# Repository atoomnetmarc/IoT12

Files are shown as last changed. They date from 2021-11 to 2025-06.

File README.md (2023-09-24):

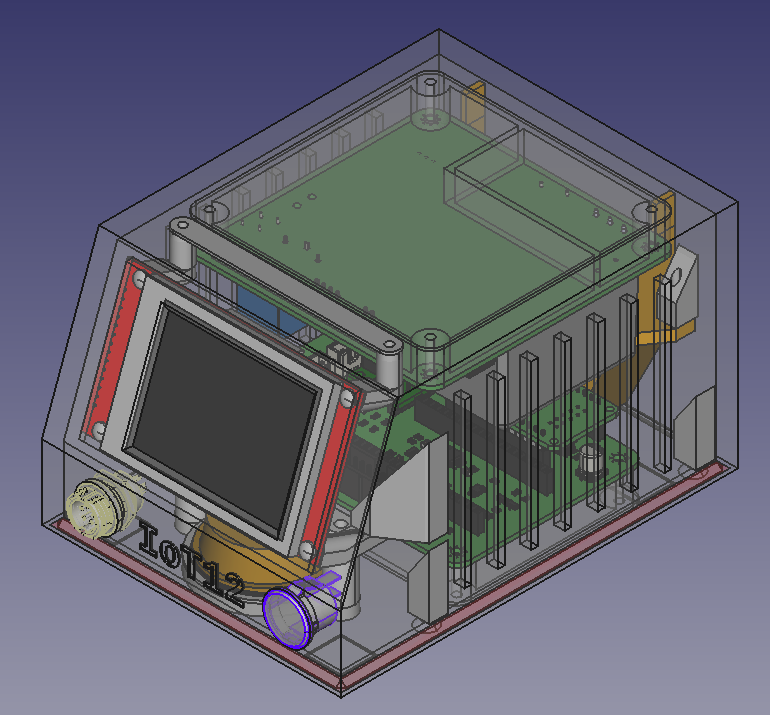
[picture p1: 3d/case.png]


# Hi!

This is an attempt at creating a soldering iron controller that uses T12 tips for a soldering iron handle with GX12-5 connector (KSGER FX9501 Handle). The pinout of the GX12-5 connector should match [this table](#control-board-j5-to-gx12-5-connector).

The name IoT12 is a portmanteau of IoT (because this soldering iron controller is connected to the internet using WiFi) and T12 (the type of soldering iron tip).

Have a look at the different elements that make up this project:

- [3d models for the case](3d/)
- [firmware for the heat controller and main processor](firmware/)
- [schematic and pcb](hardware/)

# Status

**Experimental and incomplete. Do not replicate yet.**

**You should be present at all times when using this project in case something goes wrong.**

# Assembly

You will need to 3d print all the parts mentioned in [3d](3d/README.md) directory.

You will need the 3 PCBs mentioned in the [hardware](hardware/README.md) directory.

# Cable harness

You need to crimp some JST-XH connectors and an IDC cable. Except for the IDC cable, use a wire diameter that can carry 3A. I used 0.2mm² (24 AWG, RS PRO series stranded tinned copper conductor equipment wire with PVC insulation).

## Power supply J2 to power switch

Cut 2 pieces of 14cm (5 33/64 inch) wire and crimp JST-XH pin on 1 end. Then plug into JST-XHP-2 connector. Solder the other end to a 16mm round rocker switch.

| Pin | Description | Wire color |
| --: | -- | -- |
| 1 | To power switch | Purple |
| 2 | To power switch | Purple |

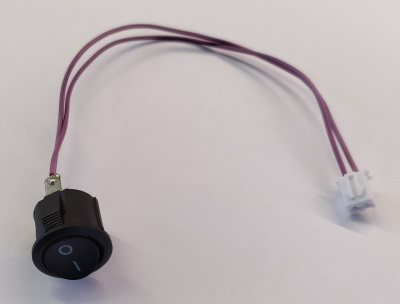
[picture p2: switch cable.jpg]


## Power supply J3 to Control Board J4

Cut 4 pieces of 14cm wire and crimp JST-XH pin on both ends. Then plug into JST-XHP-4 connector.

| Pin | Description | Wire color |
| --: | -- | -- |
| 1 | +24V | Yellow |
| 2 | +5V | Red |
| 3 | GND | Black |
| 4 | +24V ON | Pink |

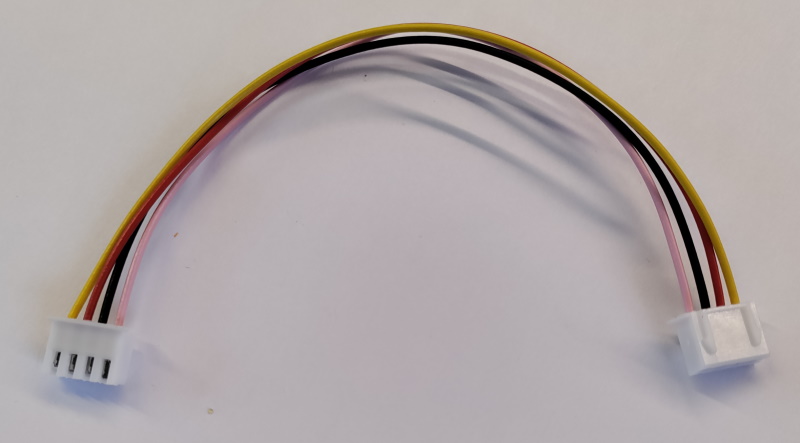
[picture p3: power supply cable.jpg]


## Control board J2 to speaker

Cut 2 pieces of 14cm wire and crimp JST-XH pin on 1 end. Then plug into JST-XHP-2 connector. Solder the other end to a 4cm speaker (4 ohm 3 watt)

| Pin | Description | Wire color |
| --: | -- | -- |
| 1 | To speaker | Brown |
| 2 | To speaker | Brown |

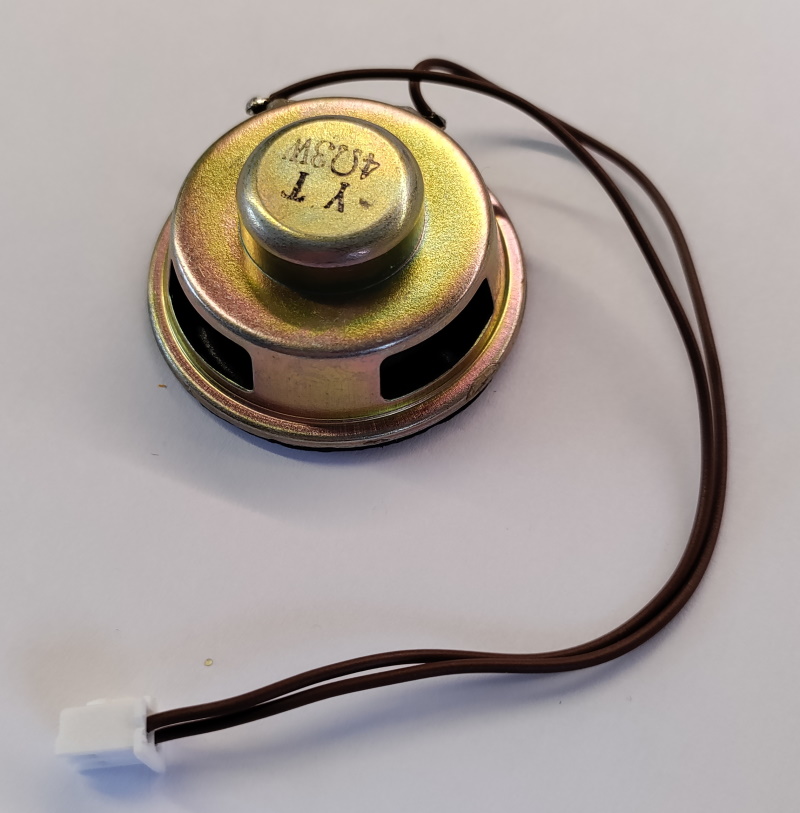
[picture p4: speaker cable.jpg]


## Control board J5 to GX12-5 connector

Cut 5 pieces of 14cm wire and crimp JST-XH pin on 1 end. Then plug into JST-XHP-52 connector. Solder other end to GX12-5 connector.

| Pin | Description | Wire color |
| --: | -- | -- |
| 1 | shake | Blue |
| 2 | NTC | White |
| 3 | ESD | Green |
| 4 | T12- | Black |
| 5 | T12+ | Red |

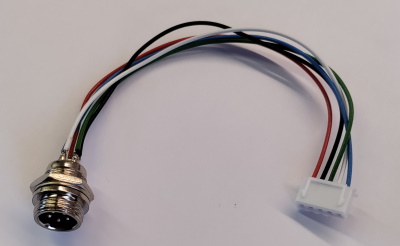
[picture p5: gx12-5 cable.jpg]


## Control board J1 to Display Adapter J1

Cut a 14 cm 14-pin 1.27mm pitch ribbon cable. Crimp a IDC-14 connector on both ends. You should orient both connectors so that one polarizing key points away from the center of the cable and the other points to the center of the cable. Please note that pin 1 of the cable should align with pin 1 on both connectors (indicated by a triangle on the connector).

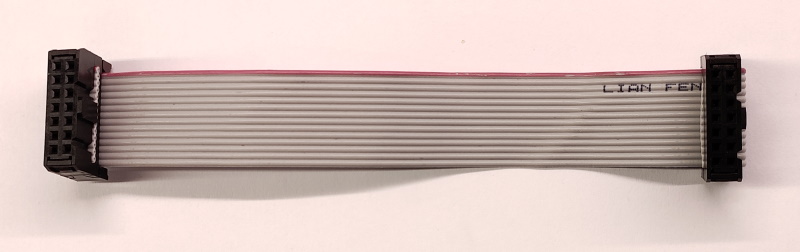
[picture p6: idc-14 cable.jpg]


# Testing

Connect a (KSGER) T12 solder iron handle with the T12 tip (really) firmly seated inside to the GX12-5 socket. The JST-XH connector should connected to the control pcb. The power supply board should be connected to to the control pcb, but not powered on.

Measure about 60kΩ between the tip of the iron and GND on the control board (J6).

Measure 1MΩ between the tip of the iron and EARTH pin at the Power supply board (J1).

Now measure some values at the solder iron connector J5.\
The heater resistor between 4 (black) and 5 (red): 8Ω.\
Not 8Ω? Now retry and really push in the T12 tip into the handle.

Switch over to measure mV and measure 4 (black) and 5 (red) again. When you have not touched the handle and tip for half an hour you should read 0mV. Grab the cold T12 tip with your hand. You should notice an increasing voltage, possibly a rise until 0.1mV. It is possible your voltmeter is not capable of measuring in the microvolt range. You can heat the tip with a flame for a few seconds to increase the voltage some more.

Measure the NTC between 4 (black) and 2 (white): 5KΩ at 22°C (71.6°F) room temperature, but resistance could vary slightly when not measuring at 22°C.

Test the tilt sensor. Point soldering iron up and measure between 1 (blue) and 3 (green). You are measuring around 250kΩ.\
Point iron down and measure a low resistance of less than 100Ω.

The soldering iron handle is now validated to be correctly connected and should function correctly.

Connect the speaker to J2 on the control board.

Connect the power switch to J2 on the power supply board.

Connect display adapter J1 to control board J1.

Modules A1 and A3 should not be plugged in yet. All other connectors are plugged in.

Apply current limited (100mA) 24V with your lab power supply to the right leg of F1 on the power supply board (and gnd on some other pin like the middle pin of U1). Apply the 24V slowly starting at 0V. Stop at 6V. Measure the 5V pin on J4 (it should be 5.2V), notice LED D4 also lit up. Continue increasing to 24V. Current should stay below 10mA. Turn off lab power supply.

When all tests went well flash [the firmware](firmware/README.md) to both A1 (ESP32) and A3 (SAMD21). Do not plug in the modules in the control board before flashing the firmware.

Plug in A1 and A3. Both USB connectors should point to the center of the control board.
Again apply current limited 24V. But now increase the limit to 250mA. At about 6V the display should turn on. Both blue LEDs on A3 and the red LED on A3 should also light up. Current is now about 200mA. Increase until 24V. Current is now about 60mA.\
Measure the 3V3 pin on J6, it should measure 3.3V.

If your power supply can handle 3.5A at 24V you could try enable heating of the soldering iron. To enable heating you must switch on the power switch connected to J2 on the power supply board.

If you came this far and all tests went well, go reward yourself with your favorite drink or snack. Happy.

# Final assembly

\<insert final assembly instructions here, something about fitting everything in the 3d printed case, hmm, maybe this is all the instuctions needed>



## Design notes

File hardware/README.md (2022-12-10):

# IoT12-hardware
Schematic and PCB files of the IoT12 solder iron temperature controller for T12 tips.

My [Kicad library](https://github.com/atoomnetmarc/ATOOMNETKICAD) is used in this project.

## [Control Board](Control%20Board/README.md)
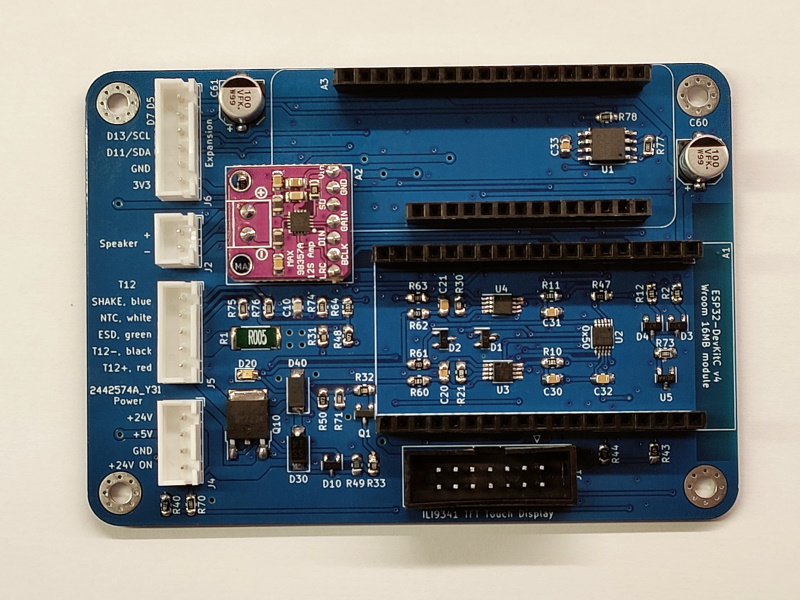
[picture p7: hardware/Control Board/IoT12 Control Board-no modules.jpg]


## [Power Supply](Power%20Supply/README.md)
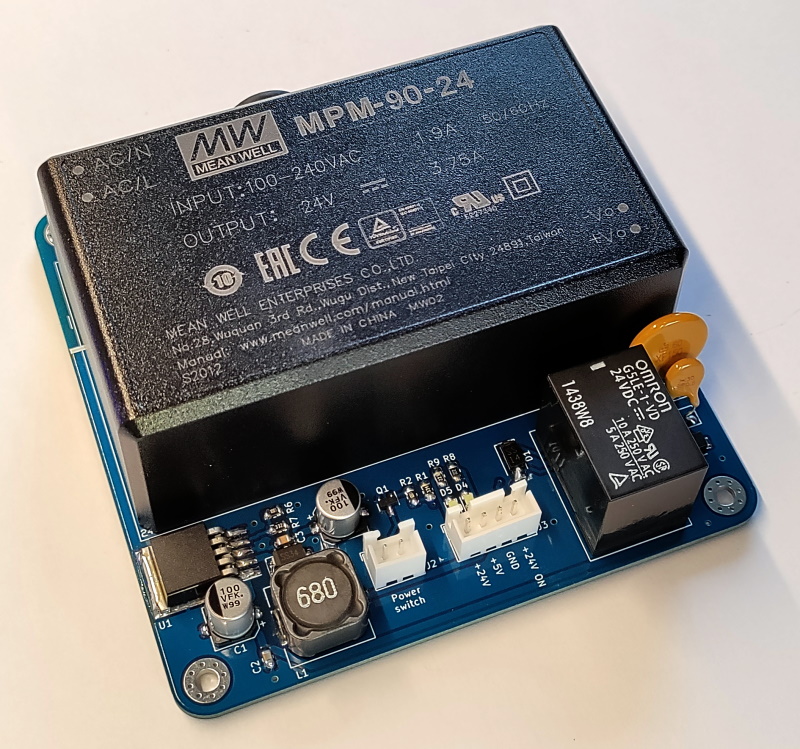
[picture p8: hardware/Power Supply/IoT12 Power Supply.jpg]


## [Display Adapter](Display%20Adapter/README.md)
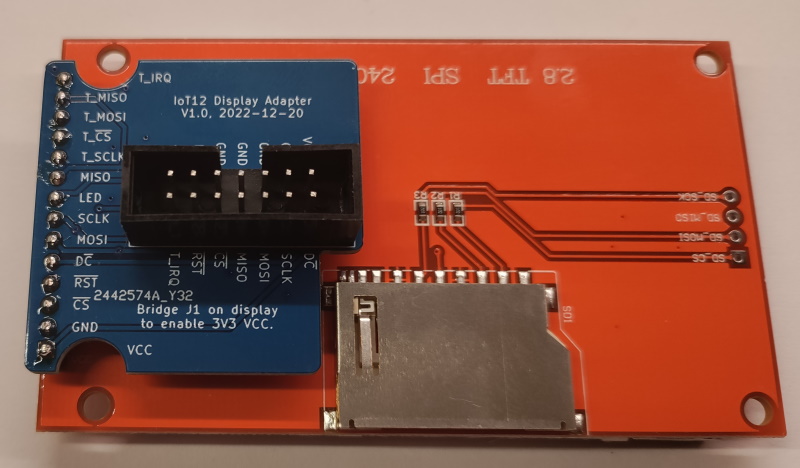
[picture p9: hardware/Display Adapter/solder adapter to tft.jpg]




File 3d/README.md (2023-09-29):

3d-models usable for the [IoT12](https://github.com/atoomnetmarc/IoT12) project.



[STLs here](stl/).

Use 6 black M3x10 counter sunk self tapping screws for mounting the lid and the C14 power socket.

Use 20 black M3x12 button head self tapping screws to mounting all other parts to the lid and the case.

Use 4 12x12mm sticky feed on bottom of lid.



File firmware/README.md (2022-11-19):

# Status

*Firmware is out of sync with the current version of control board and power supply. Grand me some time to work on things.*



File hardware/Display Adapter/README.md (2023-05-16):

Render

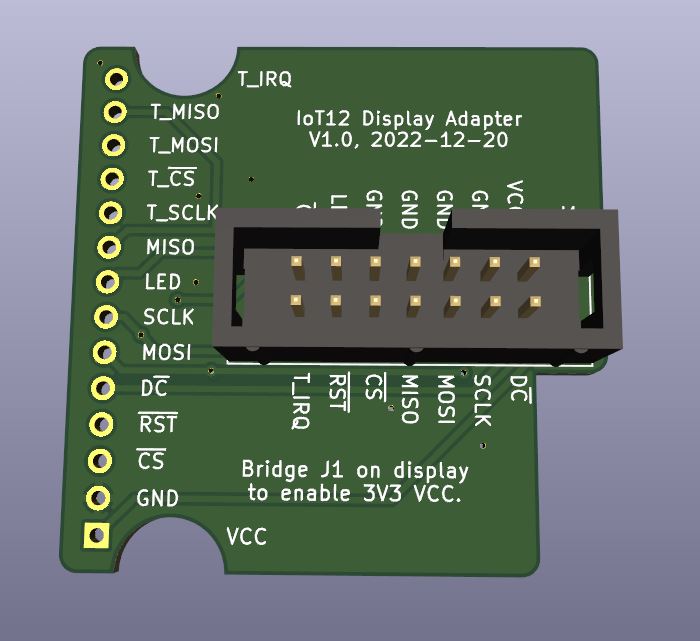
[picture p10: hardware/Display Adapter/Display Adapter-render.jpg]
Display adapter rendering


# Soldering

Yes, do it now. Use the [BOM](bom/ibom.html) for identifying the components.

Results:

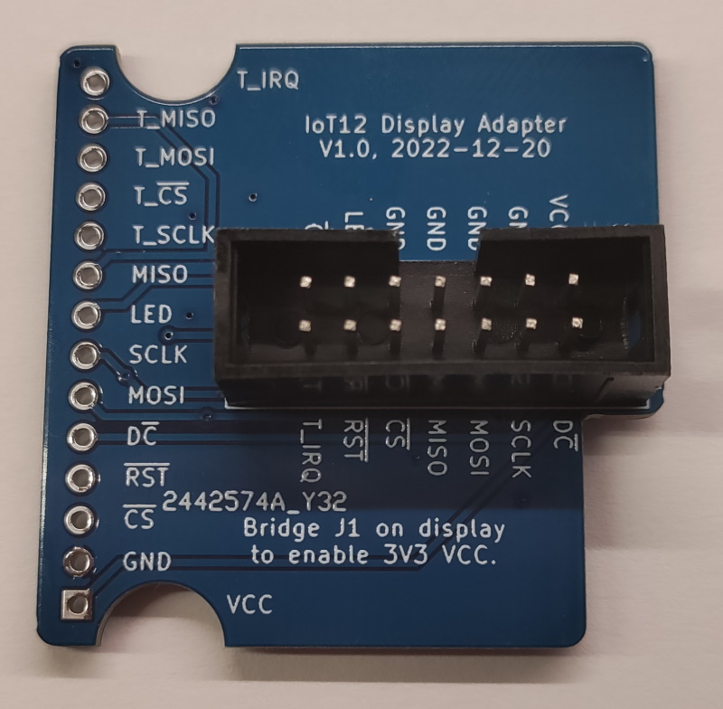
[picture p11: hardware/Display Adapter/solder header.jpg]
Yeah for soldering the only component on the BOM.


Stick a about 2.4mm high sticky pad on the bottom like this:

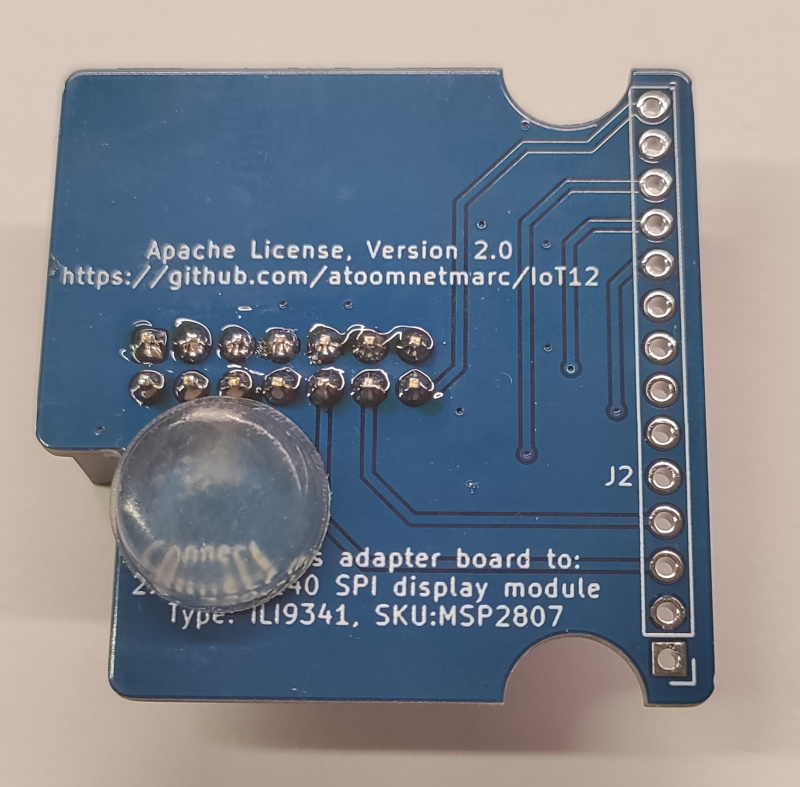
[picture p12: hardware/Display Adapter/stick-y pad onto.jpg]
I used a 4mm sticky pad.


Did you bridge J1 on the TFT pcb to enable 3.3V operation? Do that before soldering the adapter board onto the TFT.

Next, solder the adapter board onto the back of the TFT display:

Soldered adapter board to back of TFT display.



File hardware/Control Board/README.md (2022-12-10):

# Assembly instructions

Use the [interactive BOM](bom/ibom.html) to identify values and positions of the components.

Solder all small 0805 SMD resistors and capacitors.
Read special instructions for R60, R61 and R62, R63 in the schematic.

Measure all resistors and check if they are all the correct resistance.

Solder rest of SMD components.

Clean PCB.

Inspect PCB with microscope for shorted pins (in ICs). Correct when found.

Solder all through-hole components.

Clean PCB.

You now have something like this:



Apply current limited 5V to GND and +5V on J4. Almost no current should flow.

Apply current limited 3.3V to GND and 3V3 on J6. Almost no current should flow.

# Done

Done!

# Changelog

**Control board PCB version V2.2**

- Removed debug LED
- Removed 5110 LCD
- Removed rotary encoder
- Added header for 2.8" ILI9341 320x240 touch TFT
- Added relay for switching 24V
- Moved power supply circuitry to power supply PCB
- Removed small EEPROM
- Added SPI flash
- Added expansion header
- Layed out PCB again to fit on bottom lid of enclosure

**Control board PCB version V2.1**

- Swapped SDA/SCL I2C minion pins on heater controller.
- Swapped SDA/SCL I2C master pins on heater controller.
- Renamed PWM_HEAT to HEAT_PWM.
- Re-added MAX809S voltage monitor to keep ESP32 in reset if 3.3V is too low.
- Dimensioned F1 to 50% of Amax of T12-tip, see notes in schematic.
- Connected Vin ADC to after F1.
- Moved USB connector and reset button of heater controller.

**Control board PCB version V2.0**

- Replace safety features by microcontroller.
- Heating control now done by microcontroller.
- Changed shape and layout of pcb.

**Control board PCB version V1.1**

- Added explanation to schematic about using matched resistors for the instrumentation amplifiers.
- Changed gain resistors of the instrumentation amplifiers as to keep Vout under 1V at full scale input.
- Added series diode to output of voltage monitor.
- Lowered value of C2-C5 from 10nF to 1nF.
- Added D9 and D10.
- Changed value of R9 from 100R to 1k
- Added circuit to shutdown heating in case of overheating tip.

**Control board PCB version V1.0**

- First version that got made into PCB form.

# Eratta

**Control board PCB version V2.2**

No known erratum.

**Control board PCB version V2.1**

- It seems that after some use the 5110 LCD module has unreliable contacts. The LCD should be replaced by something else. PCB will need to be redesigned.
- A single occurrence of incorrect and fluctuating temperatures has been observed. Possibly caused by arcs in the power switch during power on. The power switch needs te be replaced by something else. Also the firmware needs to be made aware somehow of the situation and shutdown heating.

**Control board PCB version V2.0**

- I2C to heater controller not working. SDA/SCL are swapped. Swap them on the PCB near R55 and R56 to make the ESP32 communicate to the heater controller.
- A theme is developing :unamused:. I2C from the heater controller to the I2C EEPROM and ADC is not working. SDA/SCL are swapped. Swap them between R53, R54 and the heater controller on the bottom where the SDA/SCL traces run next to each other.
- ESP32 will lockup if power supply rise time is too slow.

**Control board PCB version V1.1**

- Overheating protection circuit not very stable. No fix.

**Control board PCB version V1.0**

- Silkscreen error in 'Solder iron connector'-block. '5, red, +.' and '4, black, ground.' are switched resulting in negative voltages for positive temperatures. Switch leads will solve this. Corrected in next PCB version.
- Gain of instrumentation amplifiers not correct.
- Programming by USB is impossible.
- Measuring temperature takes too long (20ms).

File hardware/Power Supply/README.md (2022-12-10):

Finished Power Supply PCB

This Power Supply PCB powers the IoT12 Control Board. It features a relay that can be activated by the Control Board to provide 24V power to the soldering iron. However, the relay can only be activated when the user switch on J2 is closed. This enables the user to power down the heating of the soldering iron independent of what the Control Board is able to, which is a nice feature of an internet connected soldering station.

# Warning

If you choose to replicate and use this PCB you are doing so on your own risk. It is very much possible to set your house on fire when something goes wrong or die when touching the wrong spots on the PCB.

When handling this PCB you are working with dangerous mains voltage ⚡. When touched it hurts the entire time you are dying ☠️. The bottom and top the PCB contain exposed tracks and screw terminals carry deadly mains voltage.

In conclusion, do not use this PCB.

# Assembly instructions Power Supply

Use the [interactive BOM](bom/ibom.html) to identify values and positions of the components.

Solder every SMD component. Begin with the smallest, end with the tallest.

Solder every through hole component. Begin with the smallest, end with the tallest However, do not solder the Mean Well power supply (PS1) module itself yet.

Clean the PCB.

You have now something that looks like this:

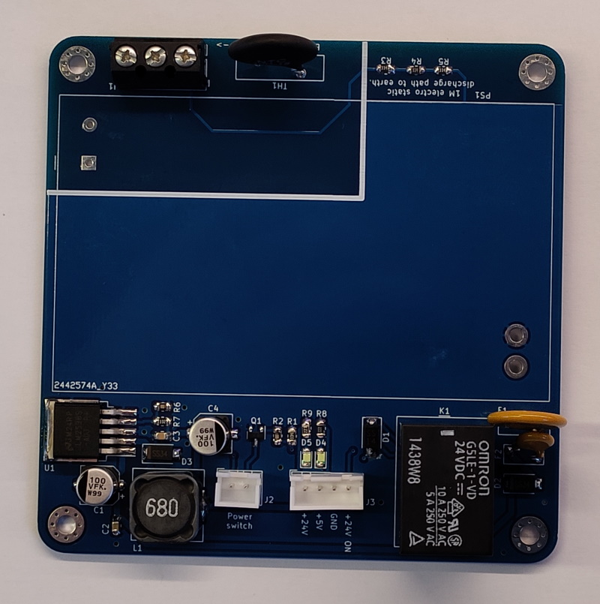
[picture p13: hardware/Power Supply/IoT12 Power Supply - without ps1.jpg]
PCB without PS1


Connect current limited (100mA) 24V on the outputs of where PS1 should be. Possibly you could connect the right leg of F1 to 24V. Current should be under 10mA. Now D4 should light up. Measure the 5V pin, it should measure about 5.2V.
Connect a jumper to J2. Connect 3V3 to gnd and the '+24V ON'-pin of J3. D5 should light up and you hear a relay click. Current increases to about 20mA.

All went well? Disconnect 24V and solder PS1.

Measure 1M between GND on J3 and Earth on J1. Measure no connection between GND on J3 and L and N on J1.

Place bottom of PCB on isolating material.

Connect leads of an unconnected grounded mains cable to J1. Use the correct screw terminal for the correct mains line. If top of PCB is not clear enough, use labels on bottom of PCB and/or consult the PCB design files.

Connect multimeter to right leg of F1 and GND to measure voltage.

⚡ Connect the mains cable to the wall socket.

LED D4 should light up again. Look, no touch, at multimeter. It should read 24V.

Disconnect the mains cable from the wall socket. Disconnect multimeter. Notice D4 is still lit. It will stop emitting light after some unit of time. The capacitors in the Mean Well power supply still contain some charge and are discharging slowly.

# Done

Done!



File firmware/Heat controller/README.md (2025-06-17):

# I2C minion

The heat controller functions as an I2C minion to our ESP32 I2C master.

Minion I2C address: **0x2A**

The minion interrupts the master by setting the HEAT_INT-pin high. The master must examine why the minion wants the attention by reading the interrupt register before reading and writing any other registers.

## Registers

There are a few registers which can be read and written to in order to communicate with and configure the heat controller. Multibyte reads and writes are [little-endian](https://en.wikipedia.org/wiki/Endianness) format.

Writes are executed by writing the register value first and then the value of the register. In case of an uint32_t or [float](https://en.wikipedia.org/wiki/Single-precision_floating-point_format) write that means writing 5 bytes in one transaction.

A register read is executed by first writing a single byte that selects the register you want to read, then reading the byte(s) of that register in one transaction. In case of a read for an uint32_t or float that means reading 4 bytes.

Some registers are saved in NVRAM. That means once set the value earlier written will be remembered between power cycles and reboots.

Registers that have something to do with temperature are all in K (kelvin) and stored in a float.

Registers that store resistance are in Ω (ohm) and are also stored in a float.

Registers that store gain are in unitless factors and stored in a float.

The firmware version register is the only register that must be read. All other are somewhat optional and operate from carefully chosen defaults when not modified.

| Register | RW  | Size | Default | Saved in NVRAM | Unit | Description |
| ---: | --- | ---: | ---: | --- | ---: | --- |
| 0x00 | R | uint32_t | | | | Firmware version |
| 0x01 | R | 4x uint32_t | | | | SAMD21 128-bit serial number  |
| 0x10 | R | uint32_t | | | | Interrupt reason |
| 0x11 | RW  | uint8_t | 0x00 | N | | Heating state |
| 0x40 | R | float | | | K | Current tip temperature |
| 0x41 | R | float | | | K | Ambient temperature |
| 0x80 | RW  | float |  373.15 | Y | K | Target tip temperature |
| 0xA0 | RW  | float |  0.0449 | Y | | Gain of Vin resistor divider  |
| 0xA1 | RW  | float | 106.1 | Y | | Gain of temperature amplifier |
| 0xA2 | RW  | float | 50.4 | Y | | Gain of current amplifier |
| 0x90 | RW  | float | 10000 | Y | Ω | NTC pullup resistor |
| 0x91 | RW  | float | 0.005 | Y | Ω | Heater shunt resistor |
| 0xF0 | RW  | uint8_t | 0x02 | Y | | I2S gain |
| 0xF1 | RW  | uint8_t | 0x00 | N | | I2S enable |
| 0xF8 | R | uint16_t |  0x1234 | | | A constant |
| 0xF9 | R | float | 3.14 | | | Mmmm, pi |

### 0x00: Firmware Version

Stored as a 32-bit integer with the bit format:
`0bXXXXXXXXX XXYYYYYYYYY YYYYYYZZZZZZ`
Presented as "X.Y.Z" where:

- X: 11-bit major version (0-2047)
- Y: 15-bit minor version (0-32767)
- Z: 6-bit patch version (0-63)

Version range: 0.0.0 to 2047.32767.63
Follows [Semantic Versioning](https://semver.org/) principles:

- Major version (X) changes indicate breaking changes
- Minor version (Y) changes add backward-compatible features
- Patch version (Z) changes are backward-compatible bug fixes

The master must:

1. Read this register during initialization
2. Halt communication if major version is incompatible
3. Only allow register writes when compatible firmware is detected

### 0x01: Serial Number

Unique 128-bit SAMD21 microcontroller serial number represented as four consecutive 32-bit words (little-endian order).

### 0x10: Interrupt Reason

32-bit register where reading clears the HEAT_INT pin and resets the register to 0.

#### Bit Definitions:

| Bit  | Name | Description |
| ---- | ---- | --- |
| 31 | Z | Heat controller rebooted |
| 30 | Y | Group A measurements available |
| 29 | X | Group B measurements available |
| 28-0 | | Reserved (ignore if set) |

#### Handling Requirements:

1. If bit Z is set:
   - Immediately read firmware version (0x00)
   - Ignore all other bits until version is verified
2. Process other bits only after firmware verification

#### Measurement Groups:

- **Group A**: Measurements taken with heater off
  (tip temperature, ambient temperature)
- **Group B**: Measurements taken with heater on
  (supply voltage, heater current)

### 0x11: Heating State

| Value | State |
| ----- | ----- |
| 0x00  | Off |
| 0x01  | On |

### 0x80: Target Tip Temperature

Maximum allowed value: 725K (451.85°C)

### 0xF0: I2S Gain

| Value | Gain |
| ----- | ---- |
| 0x02  | 9dB  |
| 0x03  | 12dB |
| 0x04  | 15dB |

### 0xF1: I2S Enable

| Value | State |
| ----- | --- |
| 0x00  | Disabled |
| 0x01  | Enabled  |

### 0xF8, 0xF9: Test Constants

Fixed values for verifying little-endian multibyte transfers:

- 0xF8: uint16_t (0x1234)
- 0xF9: float (π ≈ 3.14)

# Fuse Configuration

BOD33 enabled with hysteresis at user level 0x25

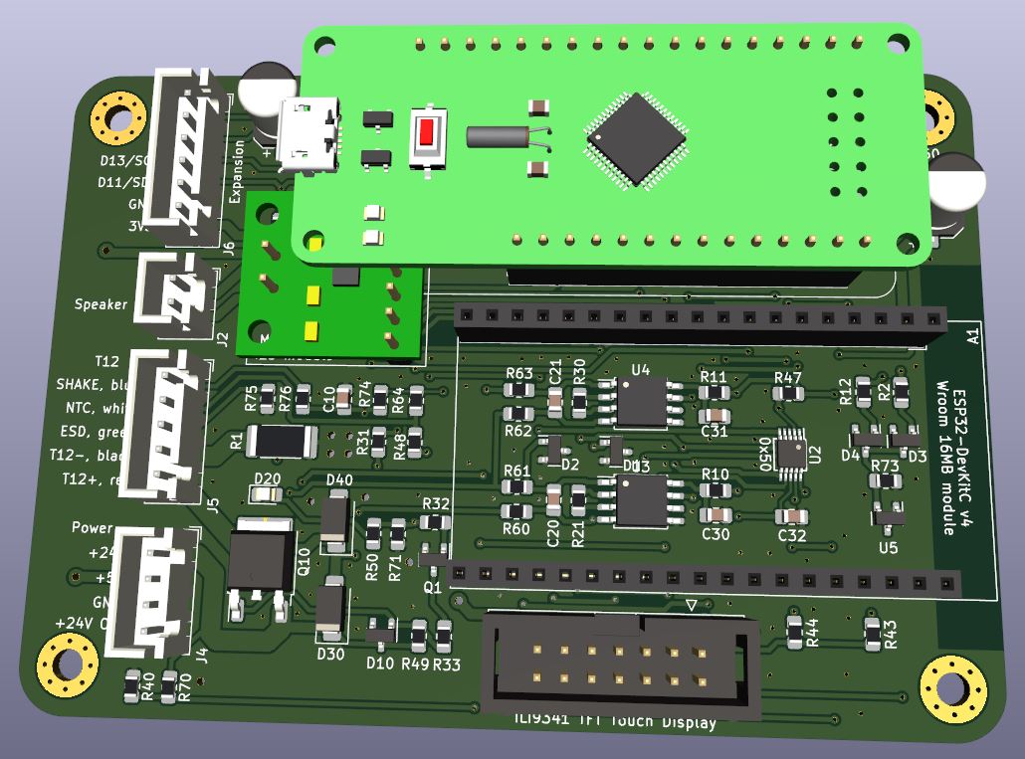
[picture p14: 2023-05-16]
hardware/Control Board/IoT12 Control Board-render.jpg

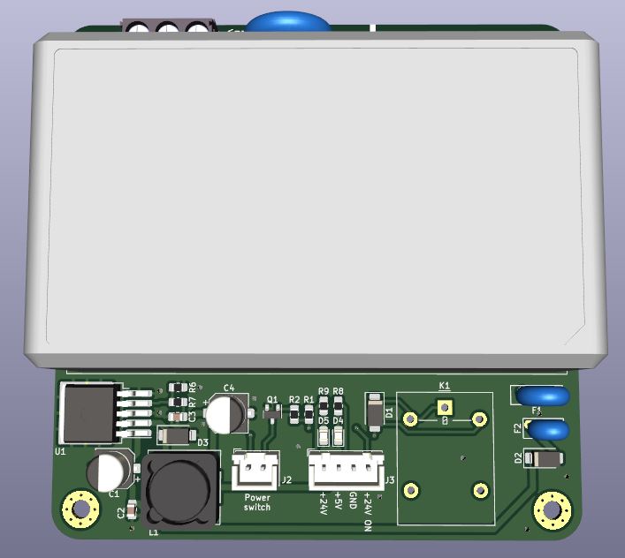
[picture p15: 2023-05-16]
hardware/Power Supply/IoT12 Power Supply-render.jpg

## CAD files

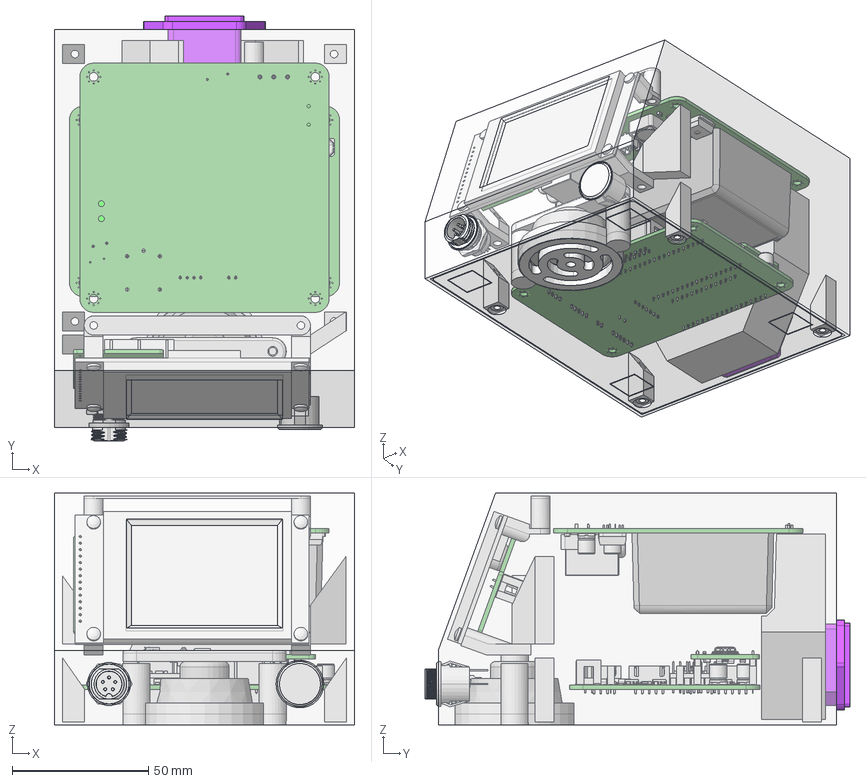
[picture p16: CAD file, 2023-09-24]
3d/Case.FCStd
110.0 x 155.7 x 85.0 mm
C14_AC-03_socket_with_fuse
GX12-5P v003
3w speaker
Rocker switch 14mm
IoT12 Power Supply PCB
IoT12 Control Board PCB
Display Adapter PCB001
m3-pan-head-12mm-001
m3-pan-head-12mm-002
m3-pan-head-12mm-003
m3-pan-head-12mm-004
lid
Speaker mount
Control board mount
case-lidscrewpost-001
case-lidscrewpost-002
case-lidscrewpost-003
case-lidscrewpost-004
Power supply mount
tft mount case top
tft-mount-left
tft-mount-right
Speaker clamp
tft mount case top bracket-001
tft mount case top bracket-002
tft mount case bottom bracket-001
tft mount case bottom bracket-002
hv-shield-screw-post
hv-shield

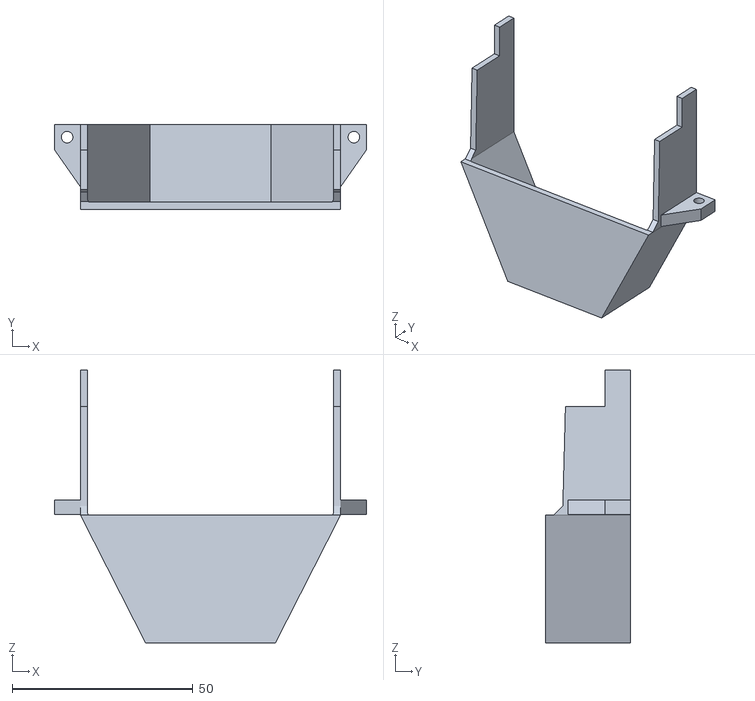
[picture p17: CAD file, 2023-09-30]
3d/stl/1x hv shield.stl
86.4 x 23.5 x 75.5

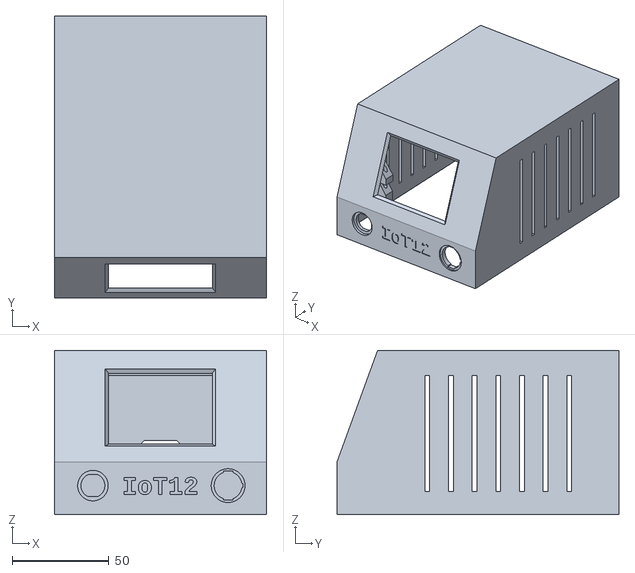
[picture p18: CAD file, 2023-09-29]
3d/stl/1x case.stl
110.0 x 146.0 x 85.0

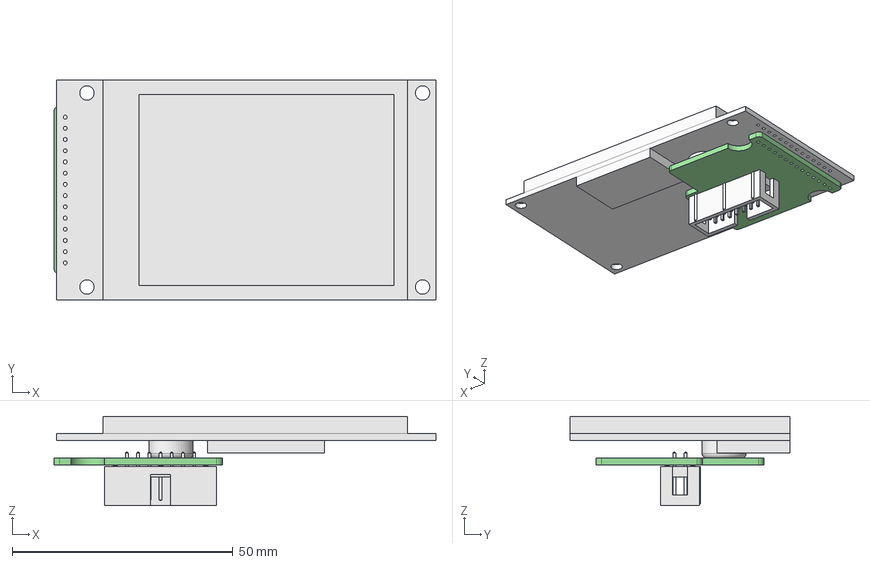
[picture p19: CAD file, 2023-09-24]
3d/tft.FCStd
86.5 x 49.9 x 20.2 mm
Display Adapter PCB

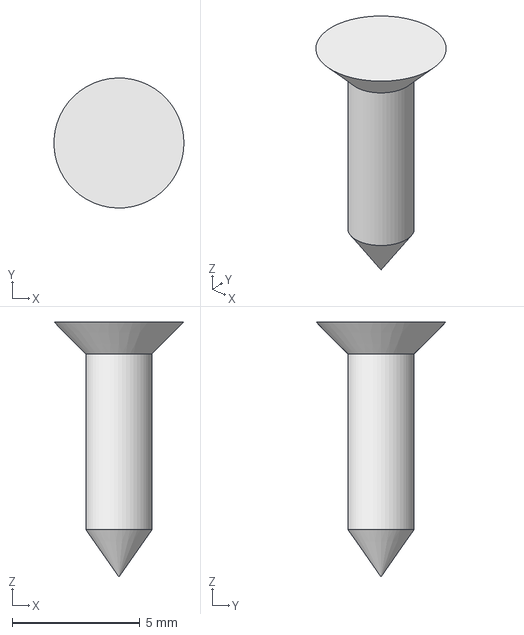
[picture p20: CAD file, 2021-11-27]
3d/m3-countersunk-10mm.FCStd
5.10 x 5.10 x 10.0 mm

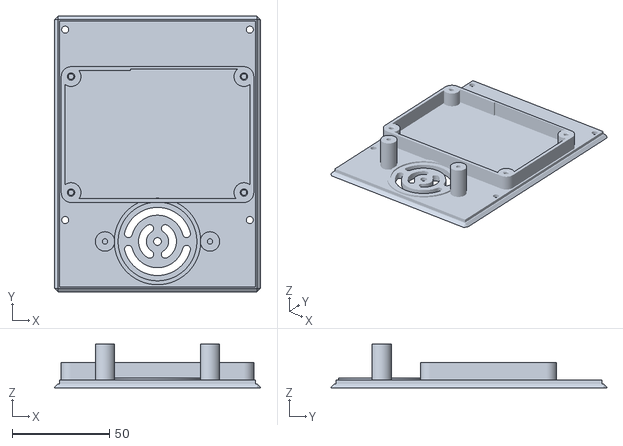
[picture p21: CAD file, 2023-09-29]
3d/stl/1x lid.stl
106.0 x 142.0 x 22.5

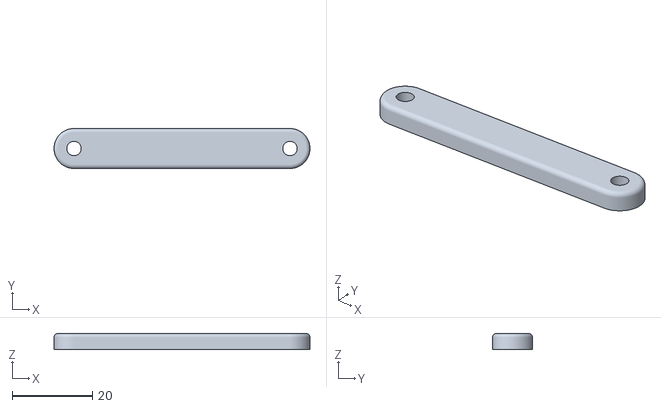
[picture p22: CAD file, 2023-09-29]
3d/stl/1x speaker clamp.stl
64.0 x 10.0 x 4.00

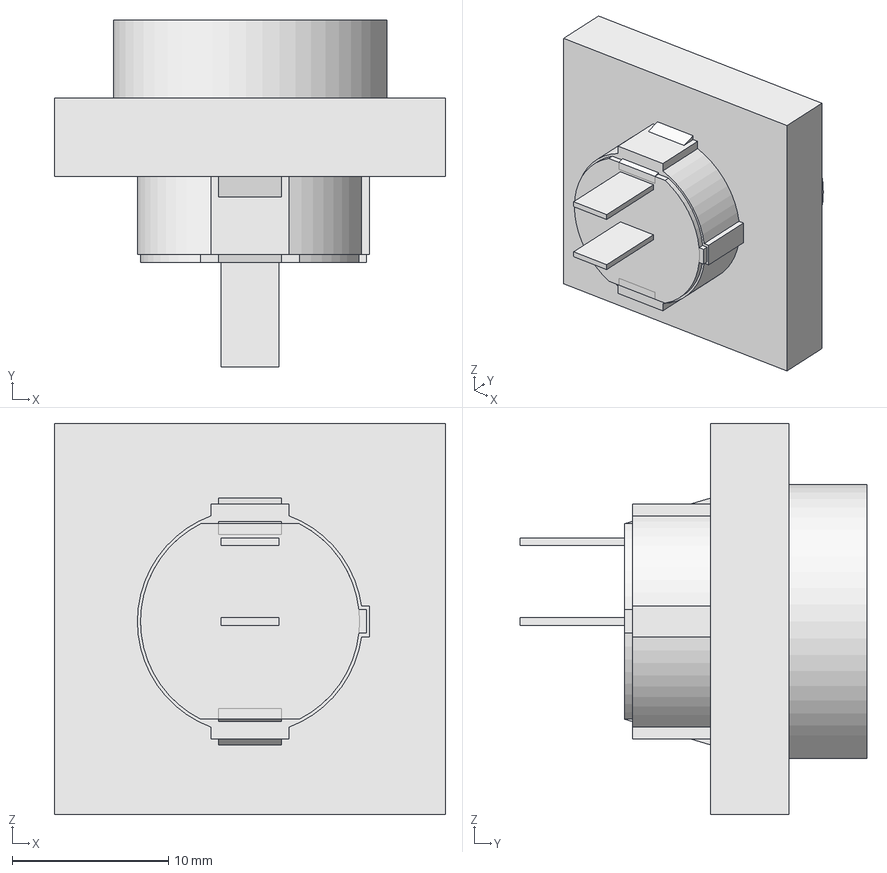
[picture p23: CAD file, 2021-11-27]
3d/switch-cutter.FCStd
25.0 x 22.2 x 25.0 mm
Rocker switch 14mm
switch-cutter

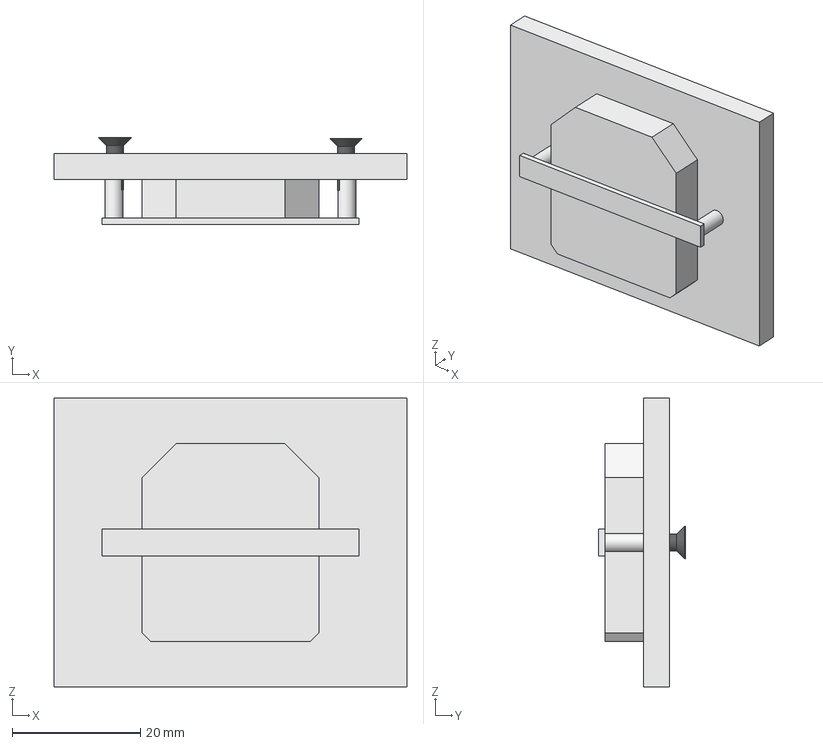
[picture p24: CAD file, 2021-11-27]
3d/socket-cutter.FCStd
55.0 x 13.5 x 45.0 mm
m3-countersunk-10mm
m3-countersunk-10mm001
C14-socker-cutter

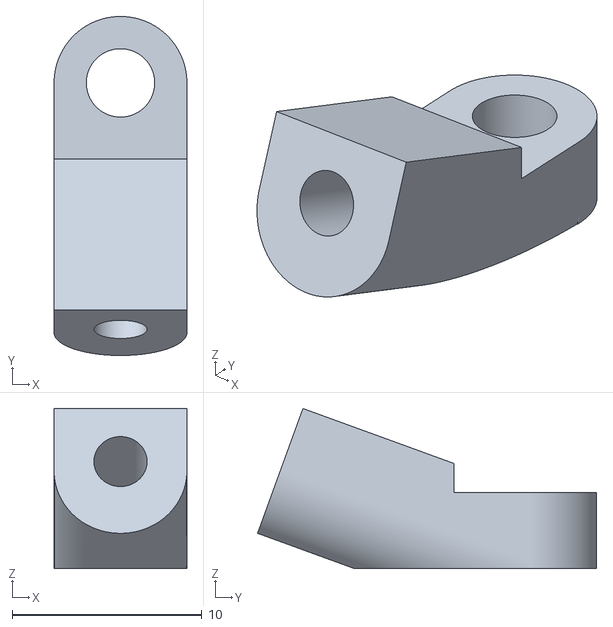
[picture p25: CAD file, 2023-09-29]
3d/stl/2x tft mount case top bracket.stl
7.00 x 17.9 x 8.43

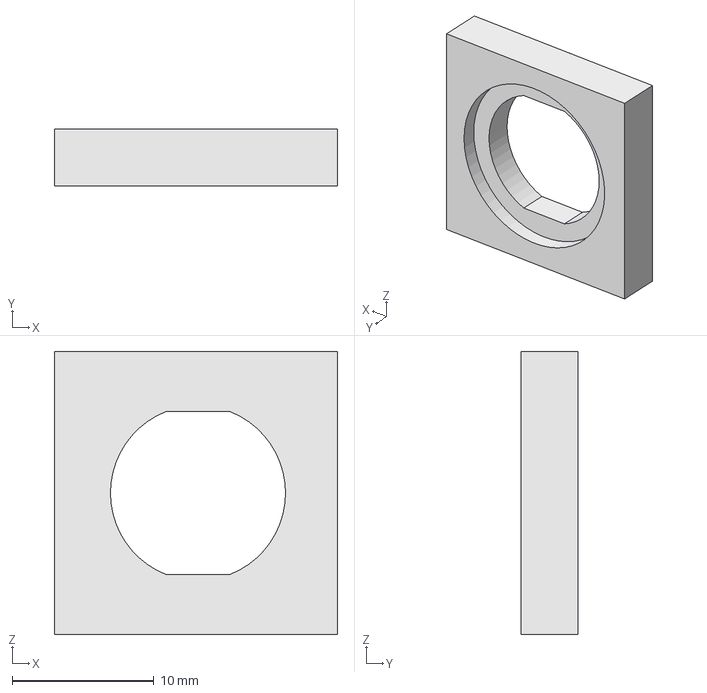
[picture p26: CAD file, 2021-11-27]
3d/gx12-cutter.FCStd
20.0 x 4.00 x 20.0 mm

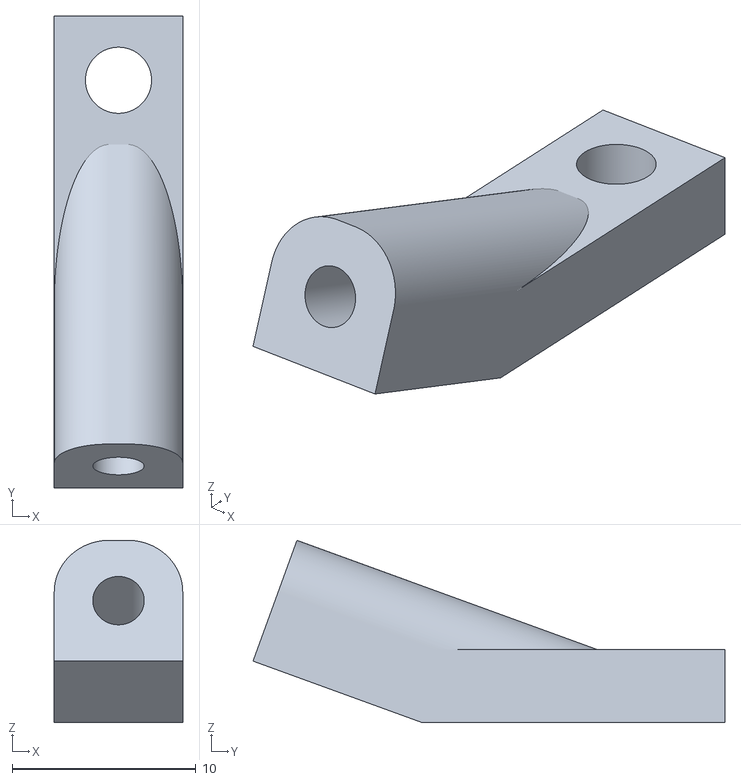
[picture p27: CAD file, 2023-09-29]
3d/stl/2x tft mount case bottom bracket.stl
7.00 x 25.7 x 9.93

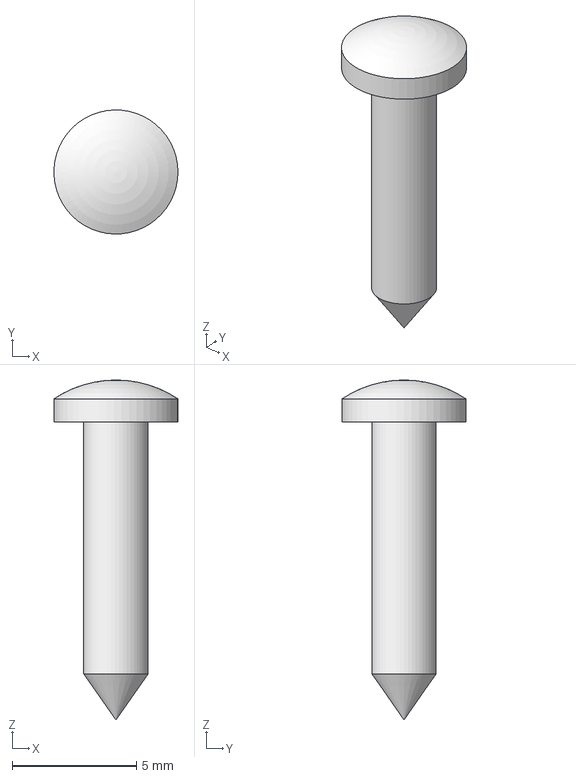
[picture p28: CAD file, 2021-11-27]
3d/m3-pan-head-12mm.FCStd
5.00 x 5.00 x 13.7 mm

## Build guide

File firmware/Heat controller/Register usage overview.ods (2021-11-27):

0x00 | 0x01 | 0x02 | 0x03 | 0x04 | 0x05 | 0x06 | 0x07 | 0x08 | 0x09 | 0x0A | 0x0B | 0x0C | 0x0D | 0x0E | 0x0F | System (stable information)
0x10 | 0x11 | 0x12 | 0x13 | 0x14 | 0x15 | 0x16 | 0x17 | 0x18 | 0x19 | 0x1A | 0x1B | 0x1C | 0x1D | 0x1E | 0x1F | System (state information)
0x20 | 0x21 | 0x22 | 0x23 | 0x24 | 0x25 | 0x26 | 0x27 | 0x28 | 0x29 | 0x2A | 0x2B | 0x2C | 0x2D | 0x2E | 0x2F | System
0x30 | 0x31 | 0x32 | 0x33 | 0x34 | 0x35 | 0x36 | 0x37 | 0x38 | 0x39 | 0x3A | 0x3B | 0x3C | 0x3D | 0x3E | 0x3F | System
0x40 | 0x41 | 0x42 | 0x43 | 0x44 | 0x45 | 0x46 | 0x47 | 0x48 | 0x49 | 0x4A | 0x4B | 0x4C | 0x4D | 0x4E | 0x4F | Measurements (temperature)
0x50 | 0x51 | 0x52 | 0x53 | 0x54 | 0x55 | 0x56 | 0x57 | 0x58 | 0x59 | 0x5A | 0x5B | 0x5C | 0x5D | 0x5E | 0x5F | Measurements (resistance)
0x60 | 0x61 | 0x62 | 0x63 | 0x64 | 0x65 | 0x66 | 0x67 | 0x68 | 0x69 | 0x6A | 0x6B | 0x6C | 0x6D | 0x6E | 0x6F | Measurements (voltage)
0x70 | 0x71 | 0x72 | 0x73 | 0x74 | 0x75 | 0x76 | 0x77 | 0x78 | 0x79 | 0x7A | 0x7B | 0x7C | 0x7D | 0x7E | 0x7F | Measurements (current)
0x80 | 0x81 | 0x82 | 0x83 | 0x84 | 0x85 | 0x86 | 0x87 | 0x88 | 0x89 | 0x8A | 0x8B | 0x8C | 0x8D | 0x8E | 0x8F | Configuration (temperature)
0x90 | 0x91 | 0x92 | 0x93 | 0x94 | 0x95 | 0x96 | 0x97 | 0x98 | 0x99 | 0x9A | 0x9B | 0x9C | 0x9D | 0x9E | 0x9F | Configuration (resistance)
0xA0 | 0xA1 | 0xA2 | 0xA3 | 0xA4 | 0xA5 | 0xA6 | 0xA7 | 0xA8 | 0xA9 | 0xAA | 0xAB | 0xAC | 0xAD | 0xAE | 0xAF | Configuration (gain)
0xB0 | 0xB1 | 0xB2 | 0xB3 | 0xB4 | 0xB5 | 0xB6 | 0xB7 | 0xB8 | 0xB9 | 0xBA | 0xBB | 0xBC | 0xBD | 0xBE | 0xBF | Configuration
0xC0 | 0xC1 | 0xC2 | 0xC3 | 0xC4 | 0xC5 | 0xC6 | 0xC7 | 0xC8 | 0xC9 | 0xCA | 0xCB | 0xCC | 0xCD | 0xCE | 0xCF | Miscellaneous
0xD0 | 0xD1 | 0xD2 | 0xD3 | 0xD4 | 0xD5 | 0xD6 | 0xD7 | 0xD8 | 0xD9 | 0xDA | 0xDB | 0xDC | 0xDD | 0xDE | 0xDF | Miscellaneous
0xE0 | 0xE1 | 0xE2 | 0xE3 | 0xE4 | 0xE5 | 0xE6 | 0xE7 | 0xE8 | 0xE9 | 0xEA | 0xEB | 0xEC | 0xED | 0xEE | 0xEF | Miscellaneous
0xF0 | 0xF1 | 0xF2 | 0xF3 | 0xF4 | 0xF5 | 0xF6 | 0xF7 | 0xF8 | 0xF9 | 0xFA | 0xFB | 0xFC | 0xFD | 0xFE | 0xFF | Miscellaneous

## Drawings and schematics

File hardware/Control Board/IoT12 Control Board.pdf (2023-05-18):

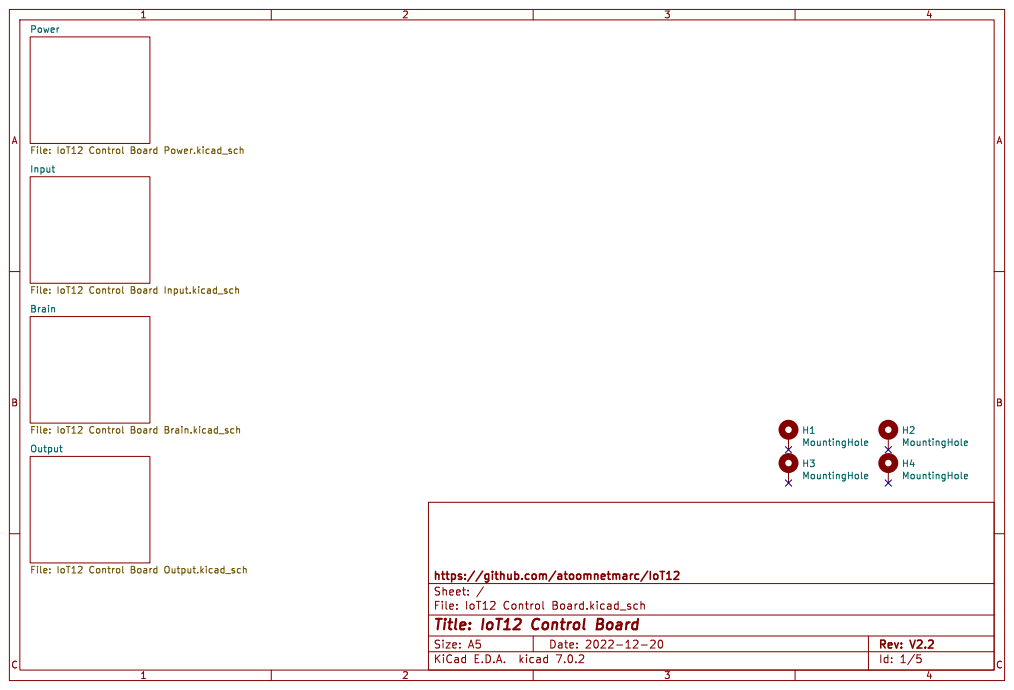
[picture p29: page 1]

Id: 1/5 Title: IoT12 Control Board

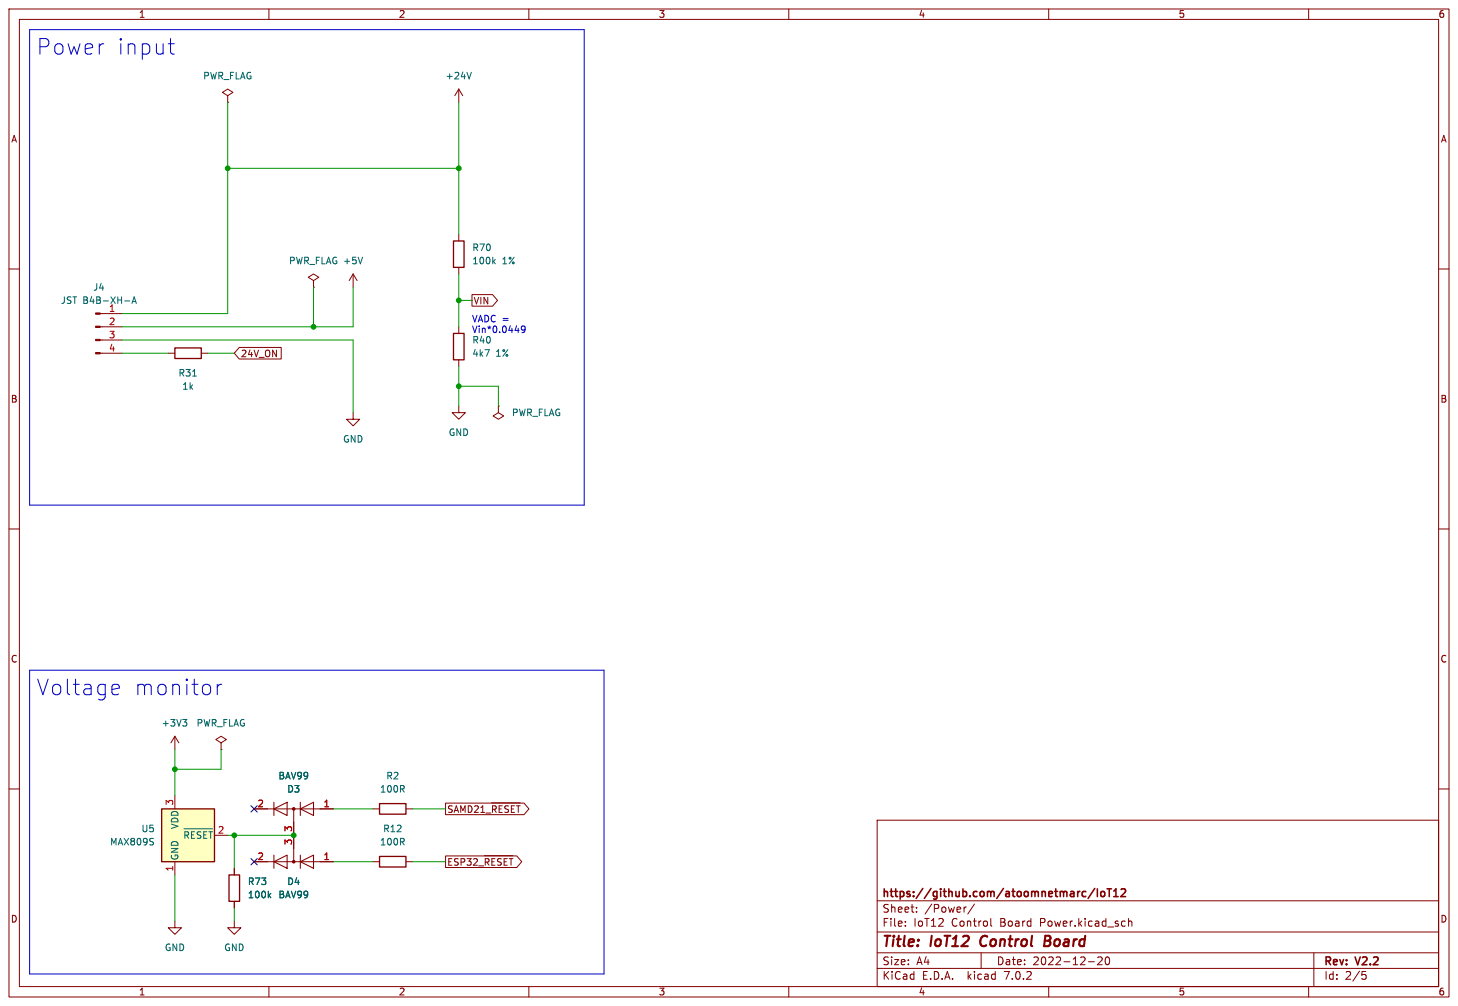
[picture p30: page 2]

Id: 2/5 Title: IoT12 Control Board

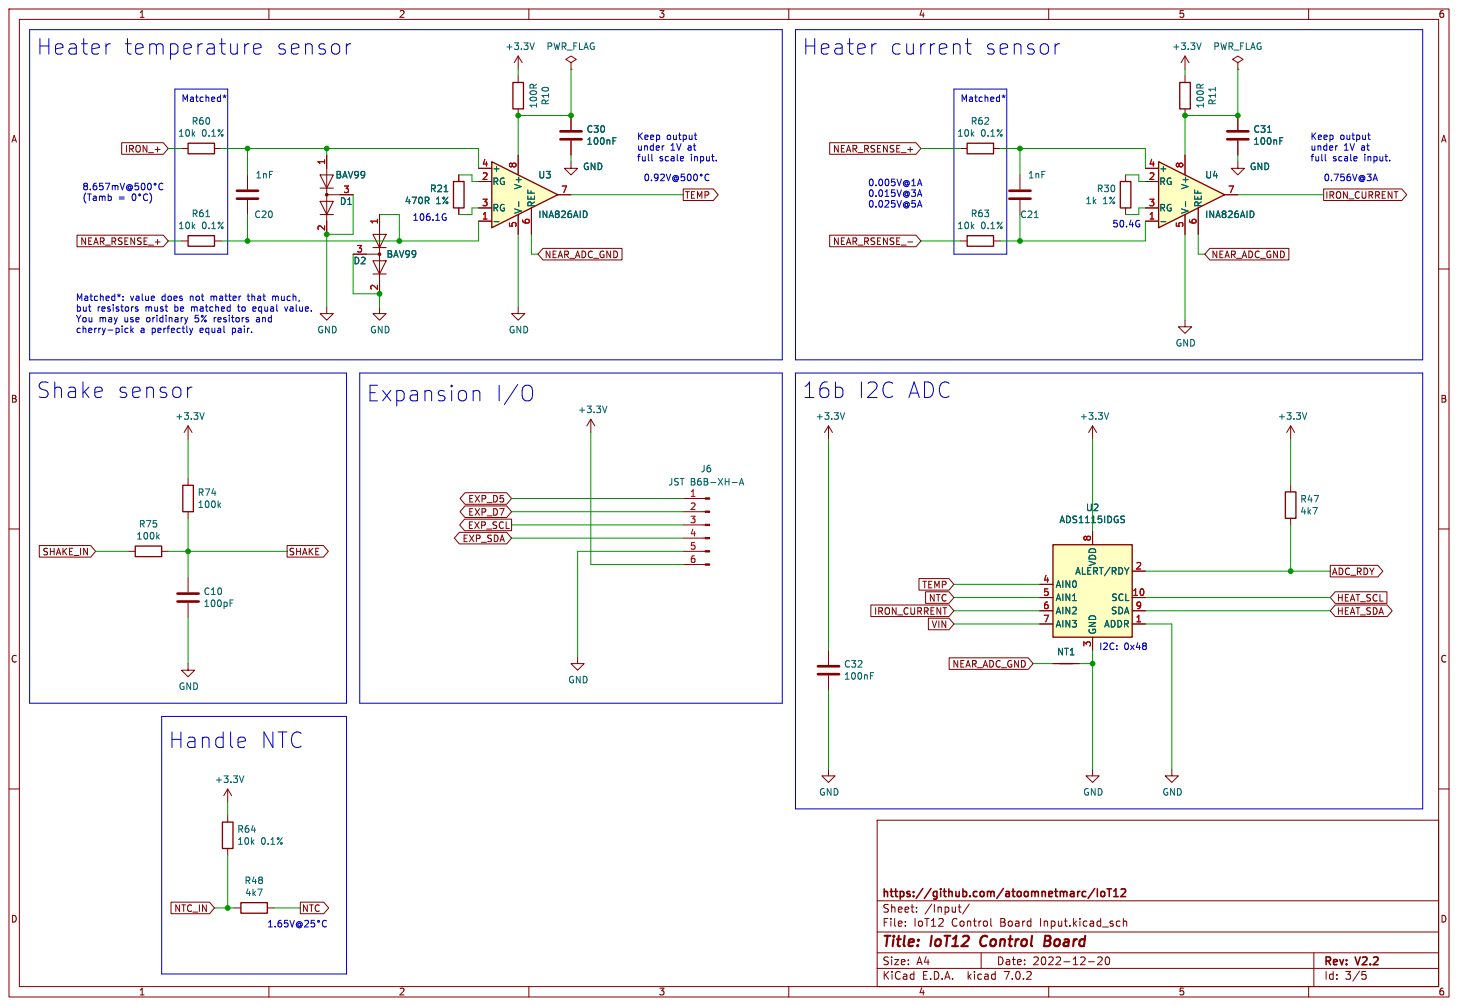
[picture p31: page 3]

Keep output under 1V at

https://github.com/atoomnetmarc/IoT12
Id: 3/5 Title: IoT12 Control Board

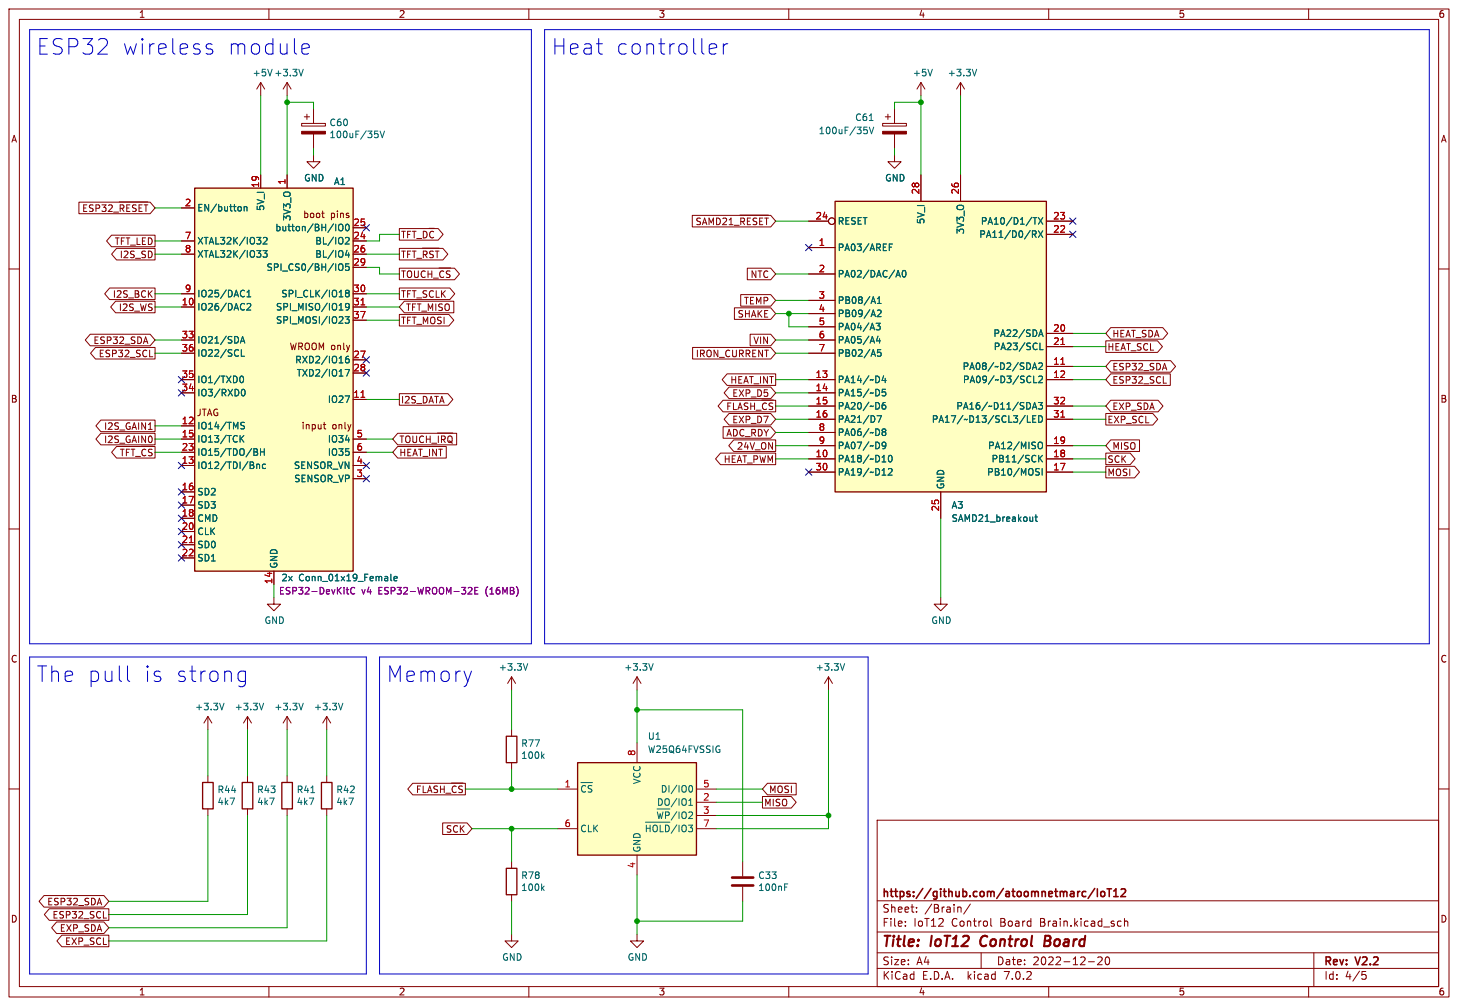
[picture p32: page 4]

The pull is strong

Id: 4/5 Title: IoT12 Control Board

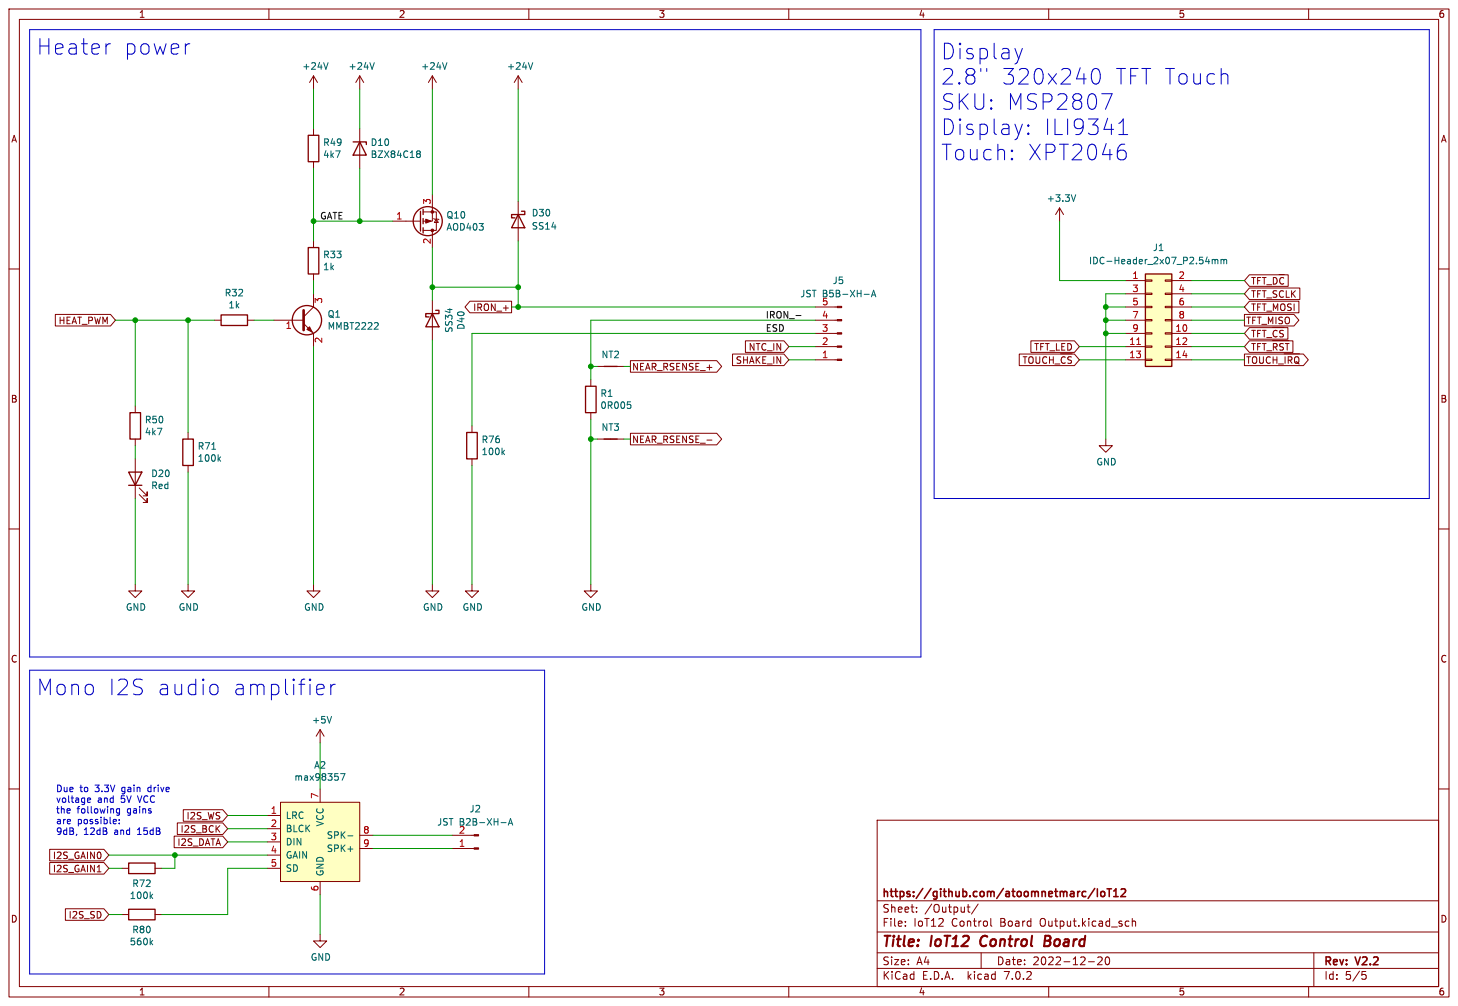
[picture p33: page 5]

Due to 3.3V gain drive
voltage and 5V VCC

https://github.com/atoomnetmarc/IoT12
Id: 5/5 Title: IoT12 Control Board

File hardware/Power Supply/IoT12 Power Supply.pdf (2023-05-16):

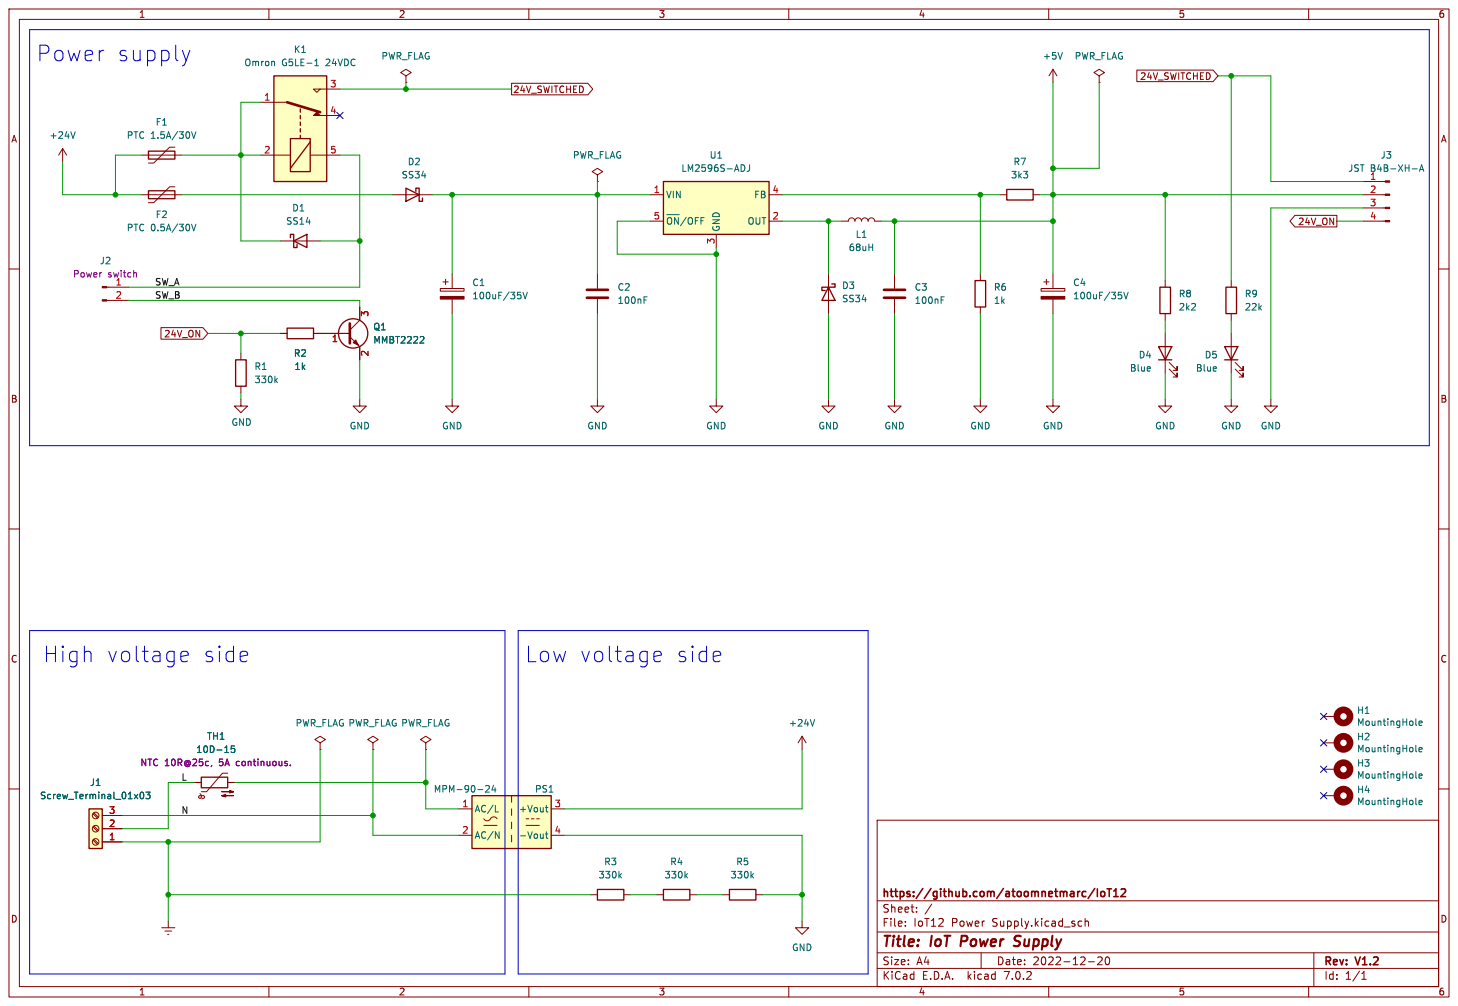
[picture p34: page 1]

Id: 1/1 Title: IoT Power Supply

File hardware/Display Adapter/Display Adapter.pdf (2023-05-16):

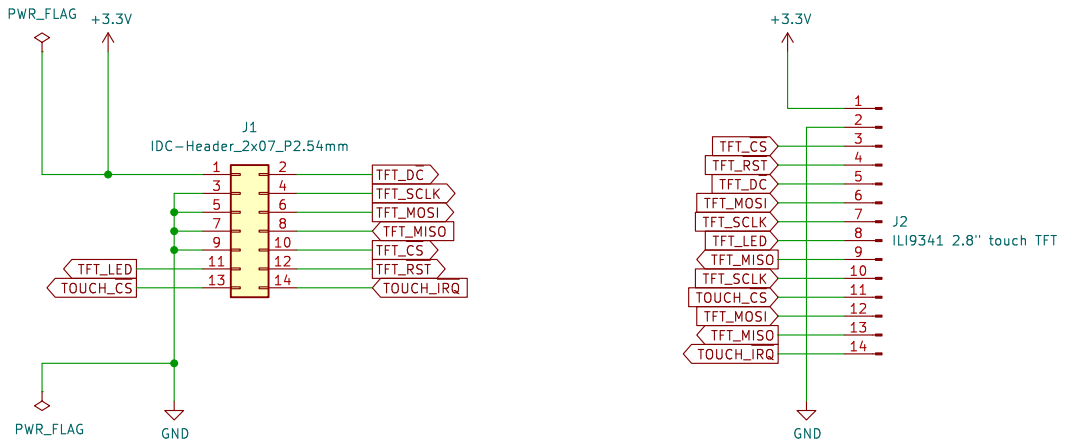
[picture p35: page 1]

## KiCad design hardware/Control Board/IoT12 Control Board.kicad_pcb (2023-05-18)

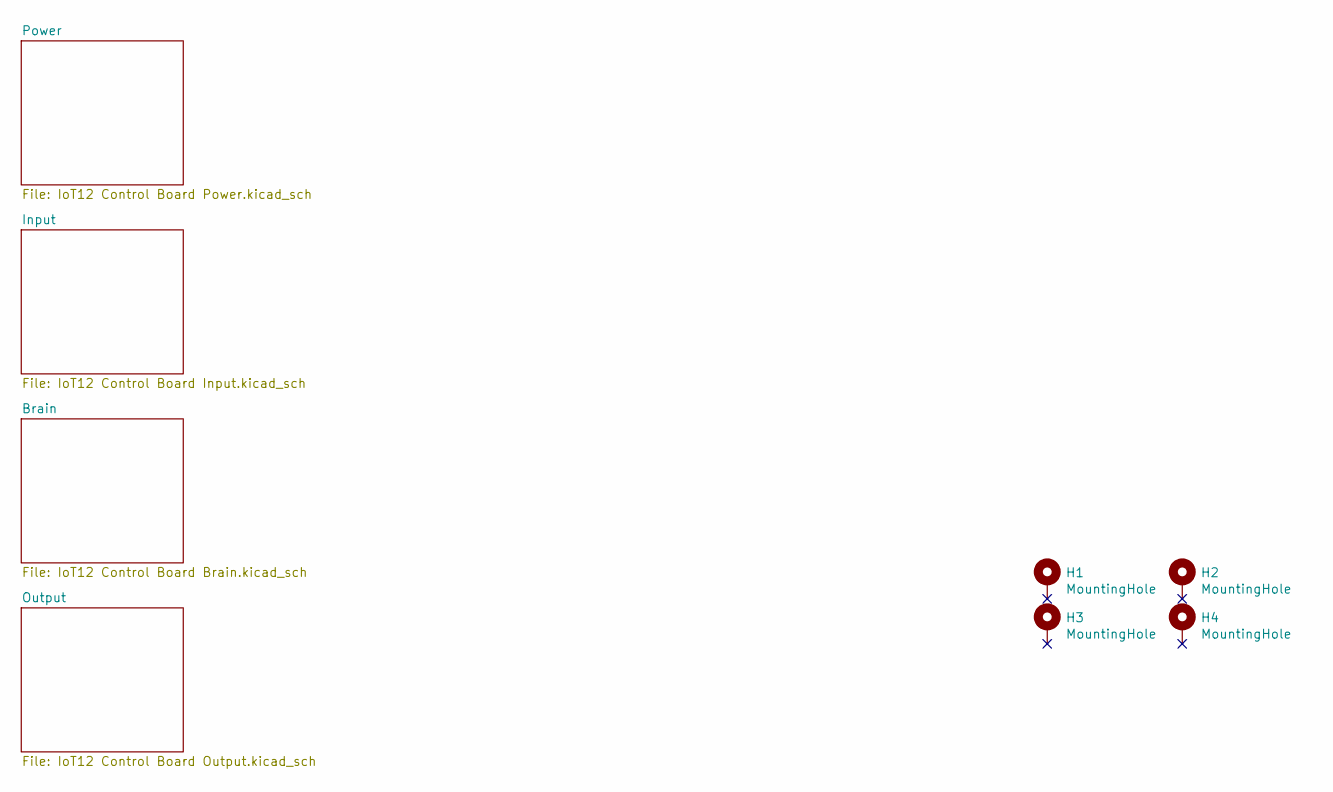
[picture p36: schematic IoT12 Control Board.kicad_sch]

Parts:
H1, H2, H3, H4: MountingHole; MountingHole_3.2mm_M3_Pad_Via

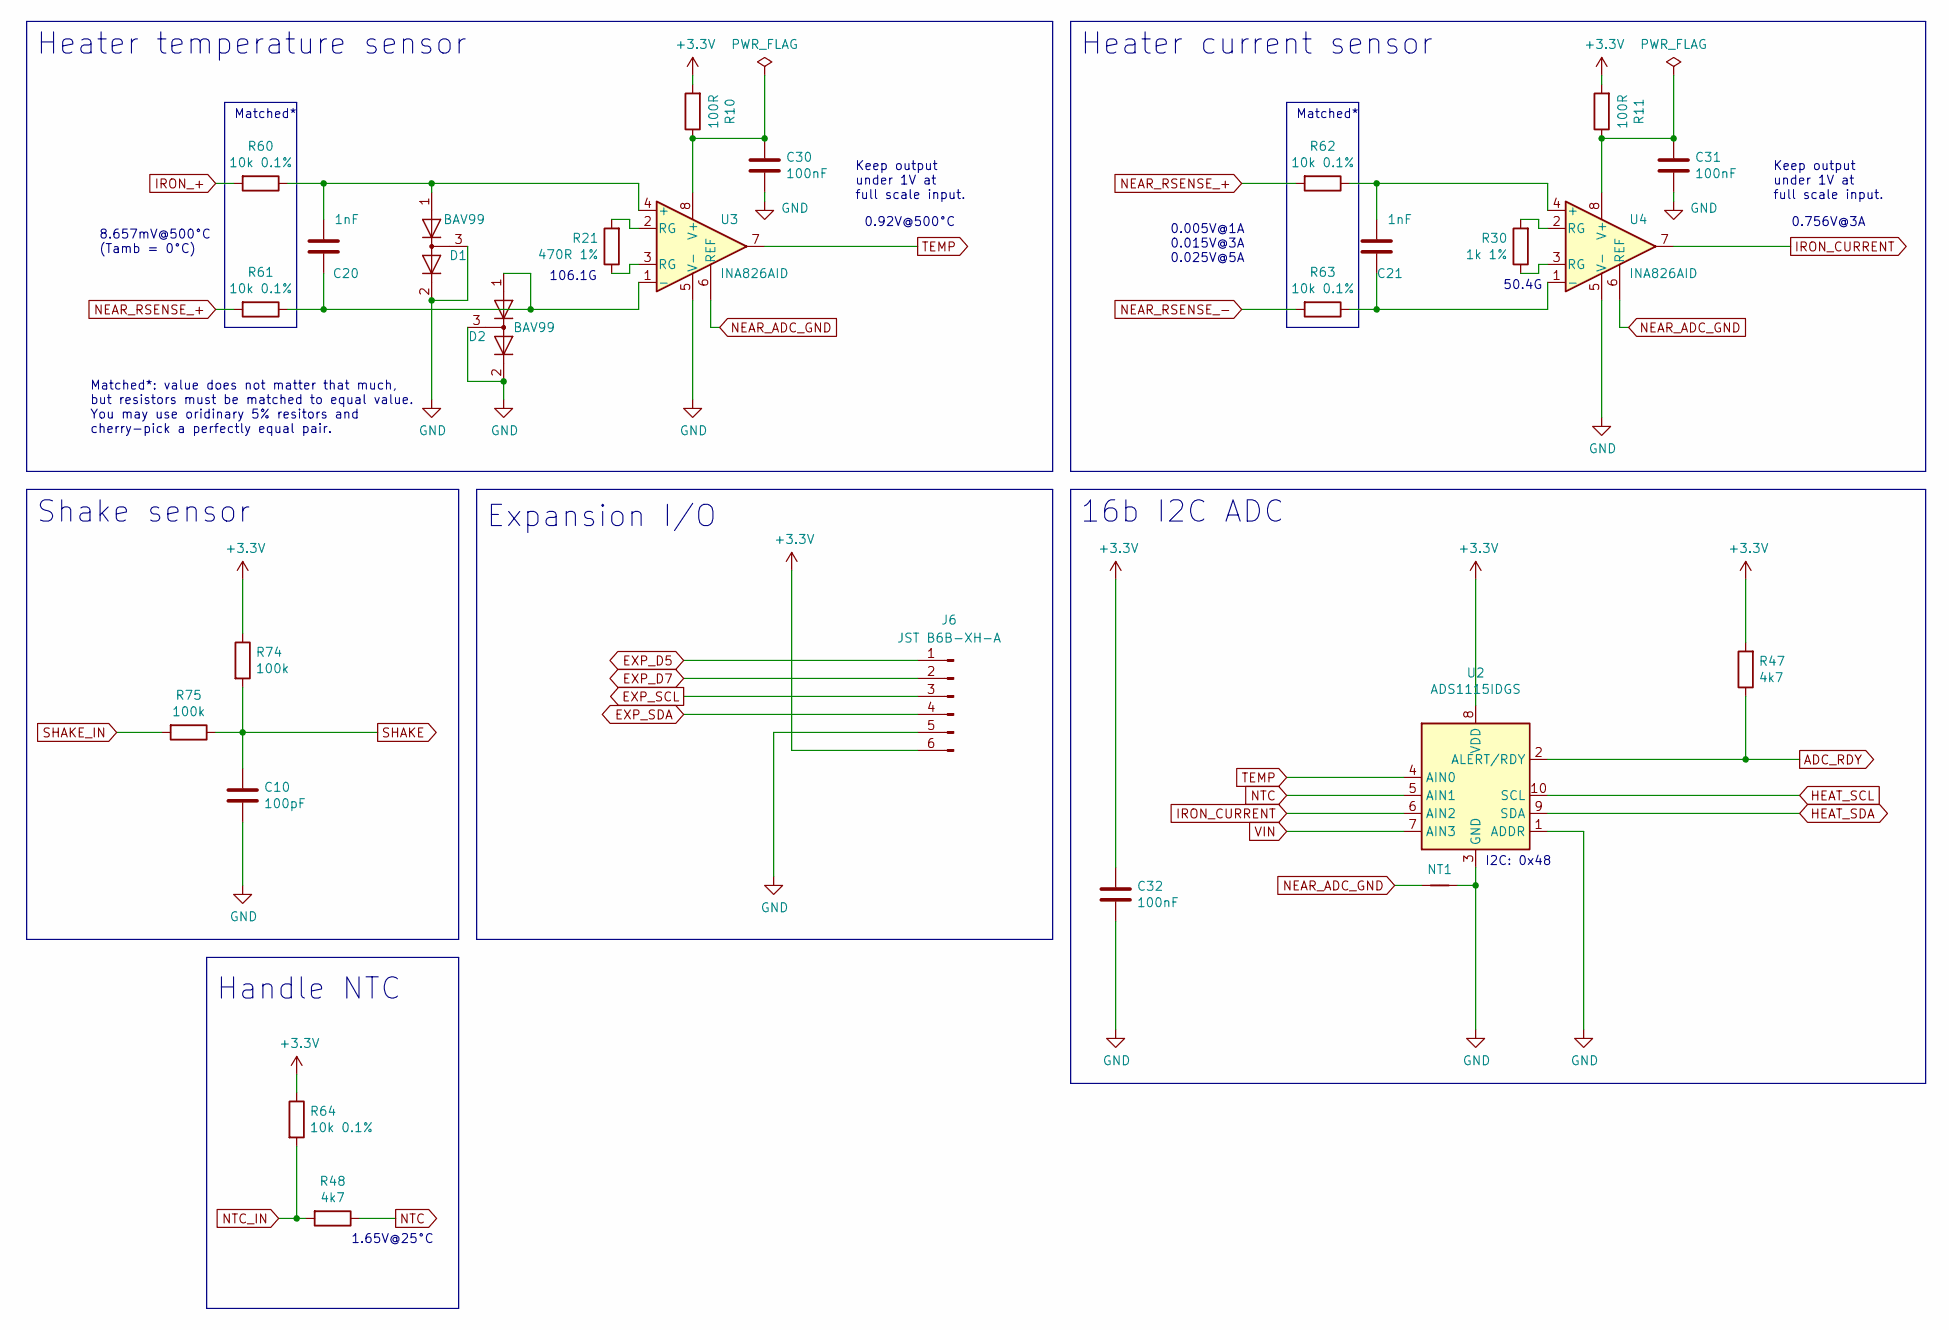
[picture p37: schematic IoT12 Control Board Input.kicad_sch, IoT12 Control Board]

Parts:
C10: 100pF; C_0805_2012Metric_Pad1.18x1.45mm_HandSolder
C20, C21: 1nF; C_0805_2012Metric_Pad1.18x1.45mm_HandSolder
C30, C31, C32: 100nF; C_0805_2012Metric_Pad1.18x1.45mm_HandSolder
D1, D2: BAV99; SOT-23
J6: JST B6B-XH-A; JST_XH_B6B-XH-A_1x06_P2.50mm_Vertical
NT1: NetTie-2_SMD_Pad0.5mm
R10, R11: 100R; R_0805_2012Metric_Pad1.20x1.40mm_HandSolder
R21: 470R 1%; R_0805_2012Metric_Pad1.20x1.40mm_HandSolder
R30: 1k 1%; R_0805_2012Metric_Pad1.20x1.40mm_HandSolder
R47, R48: 4k7; R_0805_2012Metric_Pad1.20x1.40mm_HandSolder
R60, R61, R62, R63, R64: 10k 0.1%; R_0805_2012Metric_Pad1.20x1.40mm_HandSolder
R74, R75: 100k; R_0805_2012Metric_Pad1.20x1.40mm_HandSolder
U2: ADS1115IDGS; TSSOP-10_3x3mm_P0.5mm
U3, U4: INA826AID; SOIC-8_5.23x5.23mm_P1.27mm

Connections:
+3.3V: C32.1, J6.6, R10.2, R11.2, R47.2, R64.1, R74.1, U2.8 (VDD); also elsewhere on the board
ADC_RDY: R47.1, U2.2 (ALERT/RDY); also elsewhere on the board
EXP_D5: J6.1; also elsewhere on the board
EXP_D7: J6.2; also elsewhere on the board
EXP_SCL: J6.3; also elsewhere on the board
EXP_SDA: J6.4; also elsewhere on the board
GND: C10.2, C30.2, C31.2, C32.2, D1.2 (A), D1.3 (K), D2.2 (A), D2.3 (K), J6.5, NT1.2, U2.1 (ADDR), U2.3 (GND), U3.5 (V-), U4.5 (V-); also elsewhere on the board
HEAT_SCL: U2.10 (SCL); also elsewhere on the board
HEAT_SDA: U2.9 (SDA); also elsewhere on the board
IRON_+: R60.2; also elsewhere on the board
IRON_CURRENT: U2.6 (AIN2), U4.7; also elsewhere on the board
NEAR_ADC_GND: NT1.1, U3.6 (REF), U4.6 (REF)
NEAR_RSENSE_+: R61.2, R62.2; also elsewhere on the board
NEAR_RSENSE_-: R63.2; also elsewhere on the board
NTC: R48.1, U2.5 (AIN1); also elsewhere on the board
NTC_IN: R48.2, R64.2; also elsewhere on the board
unnamed: C30.1, R10.1, U3.8 (V+)
unnamed: C31.1, R11.1, U4.8 (V+)
unnamed: R21.1, U3.3 (RG)
unnamed: R21.2, U3.2 (RG)
unnamed: R30.1, U4.3 (RG)
unnamed: R30.2, U4.2 (RG)
unnamed: C20.1, D1.1 (K), R60.1, U3.4 (+)
unnamed: C20.2, D2.1 (K), R61.1, U3.1 (-)
unnamed: C21.1, R62.1, U4.4 (+)
unnamed: C21.2, R63.1, U4.1 (-)
SHAKE: C10.1, R74.2, R75.1; also elsewhere on the board
SHAKE_IN: R75.2; also elsewhere on the board
TEMP: U2.4 (AIN0), U3.7; also elsewhere on the board
VIN: U2.7 (AIN3); also elsewhere on the board

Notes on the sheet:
I2C: 0x48
50.4G
0.005V@1A 0.015V@3A 0.025V@5A
8.657mV@500°C (Tamb = 0°C)
Heater temperature sensor
Matched*: value does not matter that much, but resistors must be matched to equal value. You may use oridinary 5% resitors and cherry-pick a perfectly equal pair.
Matched*
106.1G
0.756V@3A
Shake sensor
0.92V@500°C
16b I2C ADC
Expansion I/O
Keep output under 1V at full scale input.
Heater current sensor
1.65V@25°C
Handle NTC

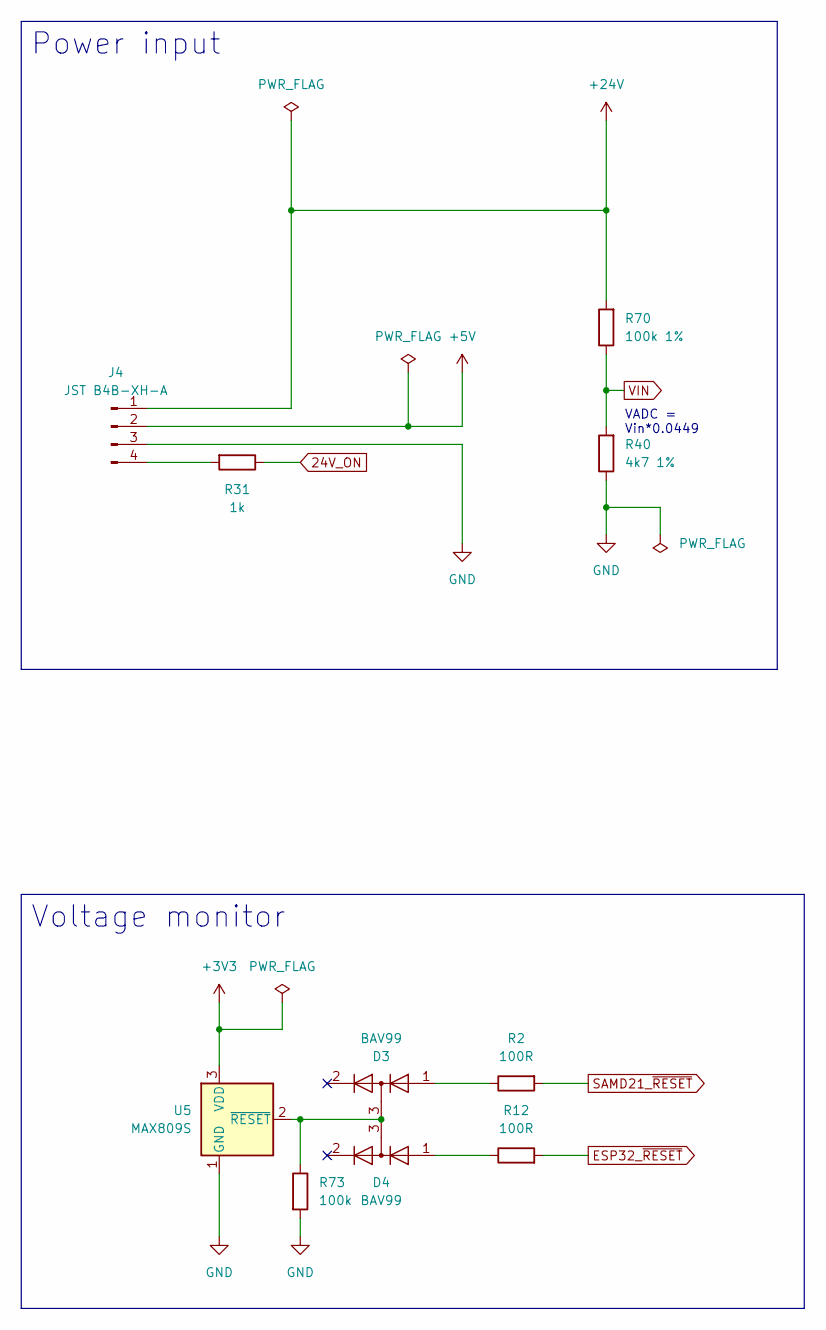
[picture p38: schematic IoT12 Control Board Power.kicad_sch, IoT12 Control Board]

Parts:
D3, D4: BAV99; SOT-23
J4: JST B4B-XH-A; JST_XH_B4B-XH-A_1x04_P2.50mm_Vertical
R2, R12: 100R; R_0805_2012Metric_Pad1.20x1.40mm_HandSolder
R31: 1k; R_0805_2012Metric_Pad1.20x1.40mm_HandSolder
R40: 4k7 1%; R_0805_2012Metric_Pad1.20x1.40mm_HandSolder
R70: 100k 1%; R_0805_2012Metric_Pad1.20x1.40mm_HandSolder
R73: 100k; R_0805_2012Metric_Pad1.20x1.40mm_HandSolder
U5: MAX809S; SOT-23

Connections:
24V_ON: R31.1; also elsewhere on the board
+3V3: U5.3 (VDD)
+5V: J4.2; also elsewhere on the board
+24V: J4.1, R70.2; also elsewhere on the board
ESP32_~RESET: R12.2; also elsewhere on the board
GND: J4.3, R40.1, R73.2, U5.1 (GND); also elsewhere on the board
unnamed: D3.1 (K), R2.1
unnamed: D4.1 (K), R12.1
unnamed: J4.4, R31.2
unnamed: D3.3 (K), D4.3 (K), R73.1, U5.2 (~RESET)
SAMD21_~RESET: R2.2; also elsewhere on the board
VIN: R40.2, R70.1; also elsewhere on the board

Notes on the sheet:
Power input
VADC = Vin*0.0449
Voltage monitor

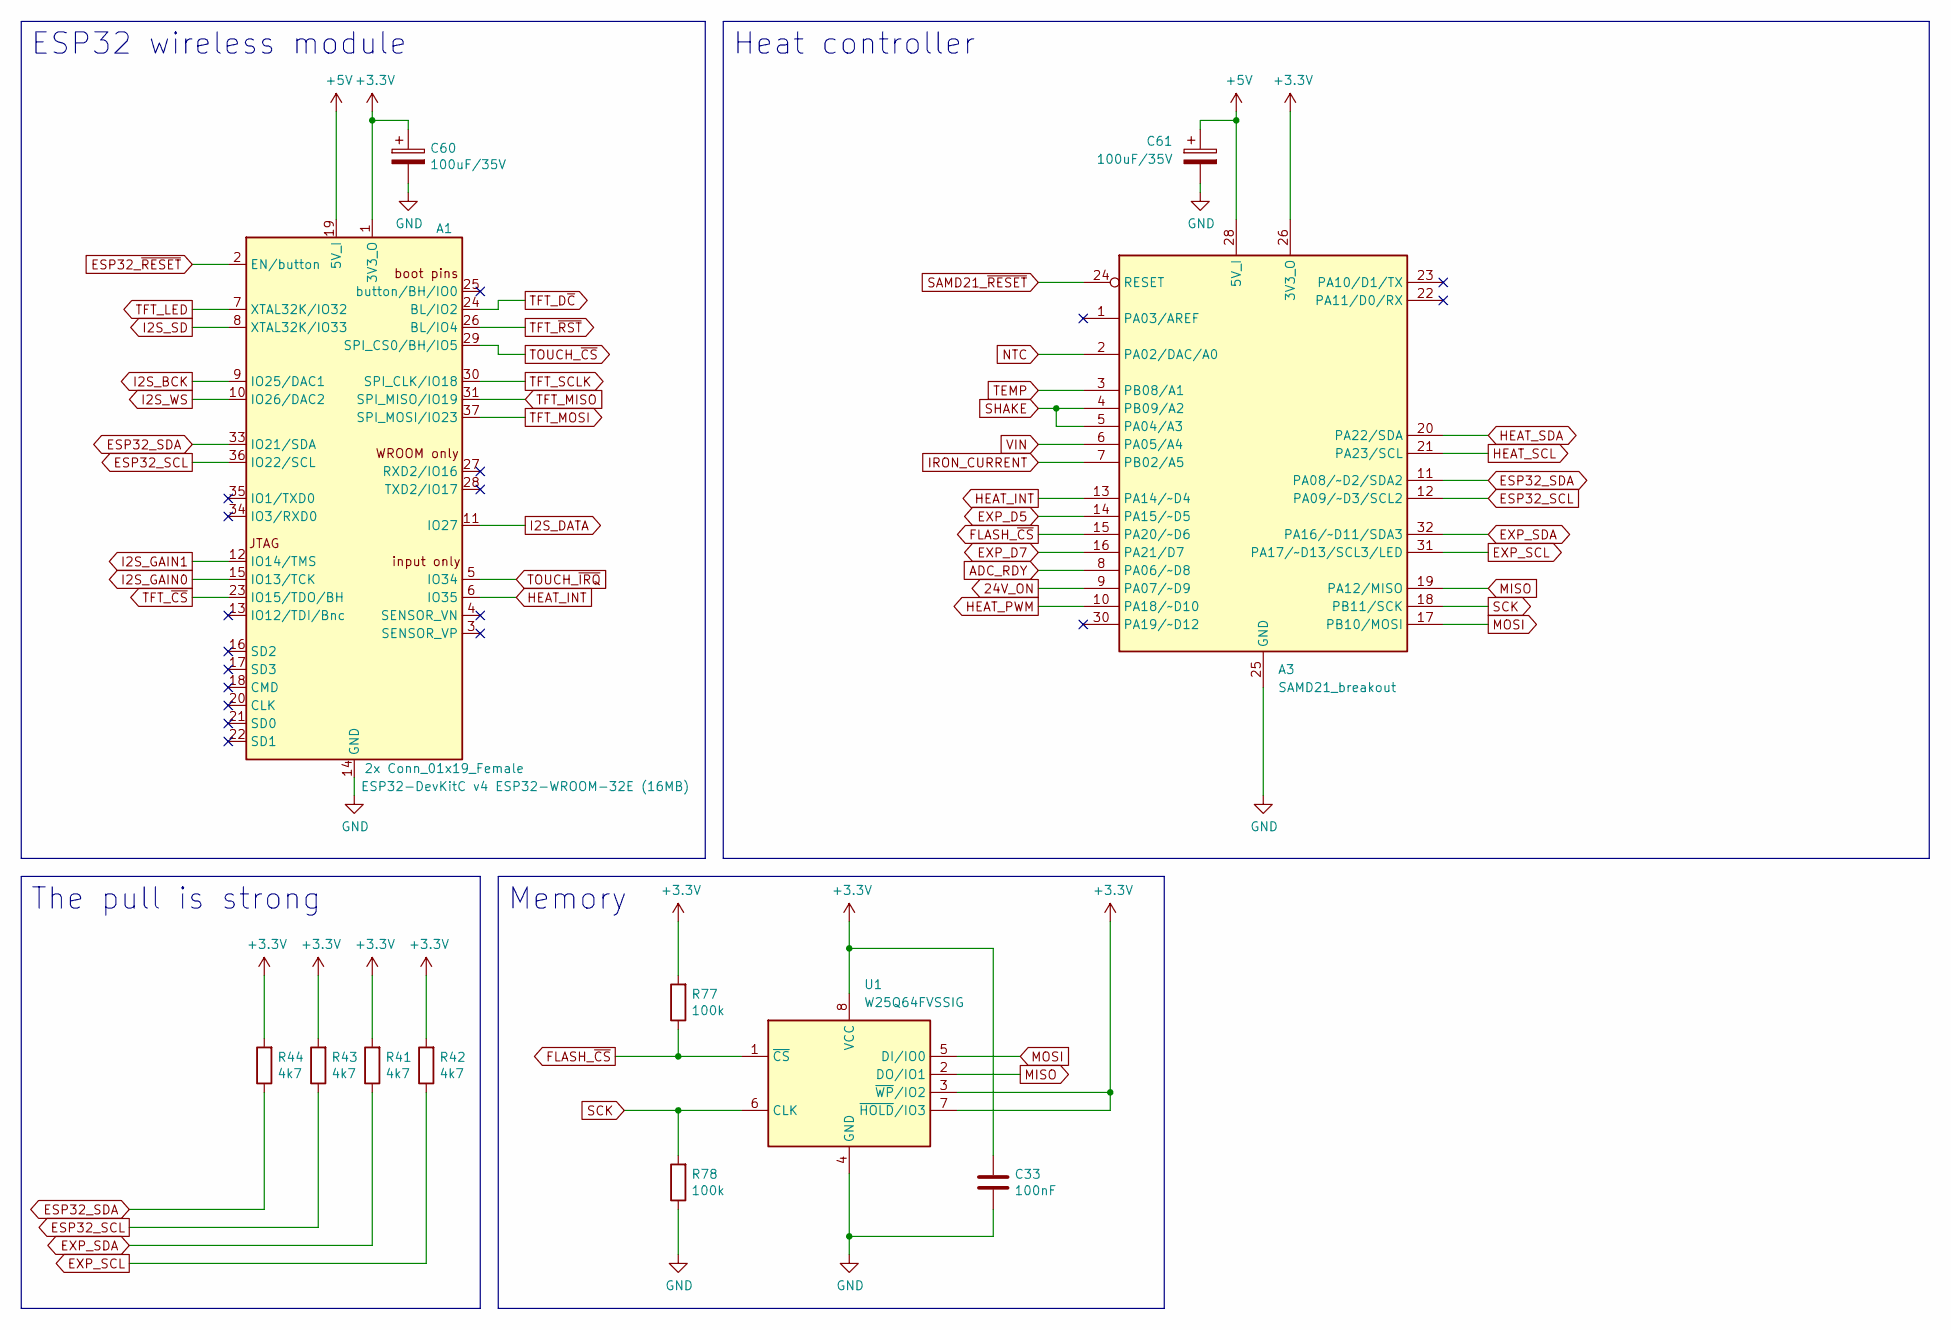
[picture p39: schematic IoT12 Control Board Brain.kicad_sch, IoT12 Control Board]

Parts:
A1: 2x Conn_01x19_Female; ESP32-DevKitC
A3: SAMD21_breakout
C33: 100nF; C_0805_2012Metric_Pad1.18x1.45mm_HandSolder
C60, C61: 100uF/35V; CP_Elec_6.3x7.7
R41, R42, R43, R44: 4k7; R_0805_2012Metric_Pad1.20x1.40mm_HandSolder
R77, R78: 100k; R_0805_2012Metric_Pad1.20x1.40mm_HandSolder
U1: W25Q64FVSSIG; SOIC-8_5.23x5.23mm_P1.27mm

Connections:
24V_ON: A3.9 (PA07/~D9); also elsewhere on the board
+3.3V: A1.1 (3V3_O), A3.26 (3V3_O), C33.1, C60.1, R41.2, R42.2, R43.2, R44.2, R77.2, U1.3 (~WP/IO2), U1.7 (~HOLD/IO3), U1.8 (VCC); also elsewhere on the board
+5V: A1.19 (5V_I), A3.28 (5V_I), C61.1; also elsewhere on the board
ADC_RDY: A3.8 (PA06/~D8); also elsewhere on the board
ESP32_SCL: A1.36 (IO22/SCL), A3.12 (PA09/~D3/SCL2), R43.1
ESP32_SDA: A1.33 (IO21/SDA), A3.11 (PA08/~D2/SDA2), R44.1
ESP32_~RESET: A1.2 (EN/button); also elsewhere on the board
EXP_D5: A3.14 (PA15/~D5); also elsewhere on the board
EXP_D7: A3.16 (PA21/D7); also elsewhere on the board
EXP_SCL: A3.31 (PA17/~D13/SCL3/LED), R42.1; also elsewhere on the board
EXP_SDA: A3.32 (PA16/~D11/SDA3), R41.1; also elsewhere on the board
FLASH_~CS: A3.15 (PA20/~D6), R77.1, U1.1 (~CS)
GND: A1.14 (GND), A1.32 (GND), A1.38 (GND), A3.25 (GND), A3.29 (GND), C33.2, C60.2, C61.2, R78.1, U1.4 (GND); also elsewhere on the board
HEAT_INT: A1.6 (IO35), A3.13 (PA14/~D4)
HEAT_PWM: A3.10 (PA18/~D10); also elsewhere on the board
HEAT_SCL: A3.21 (PA23/SCL); also elsewhere on the board
HEAT_SDA: A3.20 (PA22/SDA); also elsewhere on the board
I2S_BCK: A1.9 (IO25/DAC1); also elsewhere on the board
I2S_DATA: A1.11 (IO27); also elsewhere on the board
I2S_GAIN0: A1.15 (IO13/TCK); also elsewhere on the board
I2S_GAIN1: A1.12 (IO14/TMS); also elsewhere on the board
I2S_SD: A1.8 (XTAL32K/IO33); also elsewhere on the board
I2S_WS: A1.10 (IO26/DAC2); also elsewhere on the board
IRON_CURRENT: A3.7 (PB02/A5); also elsewhere on the board
MISO: A3.19 (PA12/MISO), U1.2 (DO/IO1)
MOSI: A3.17 (PB10/MOSI), U1.5 (DI/IO0)
NTC: A3.2 (PA02/DAC/A0); also elsewhere on the board
SAMD21_~RESET: A3.24 (RESET); also elsewhere on the board
SCK: A3.18 (PB11/SCK), R78.2, U1.6 (CLK)
SHAKE: A3.4 (PB09/A2), A3.5 (PA04/A3); also elsewhere on the board
TEMP: A3.3 (PB08/A1); also elsewhere on the board
TFT_D~C: A1.24 (BL/IO2); also elsewhere on the board
TFT_LED: A1.7 (XTAL32K/IO32); also elsewhere on the board
TFT_MISO: A1.31 (SPI_MISO/IO19); also elsewhere on the board
TFT_MOSI: A1.37 (SPI_MOSI/IO23); also elsewhere on the board
TFT_SCLK: A1.30 (SPI_CLK/IO18); also elsewhere on the board
TFT_~CS: A1.23 (IO15/TDO/BH); also elsewhere on the board
TFT_~RST: A1.26 (BL/IO4); also elsewhere on the board
TOUCH_~CS: A1.29 (SPI_CS0/BH/IO5); also elsewhere on the board
TOUCH_~IRQ: A1.5 (IO34); also elsewhere on the board
VIN: A3.6 (PA05/A4); also elsewhere on the board

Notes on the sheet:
The pull is strong
Memory
Heat controller
ESP32 wireless module

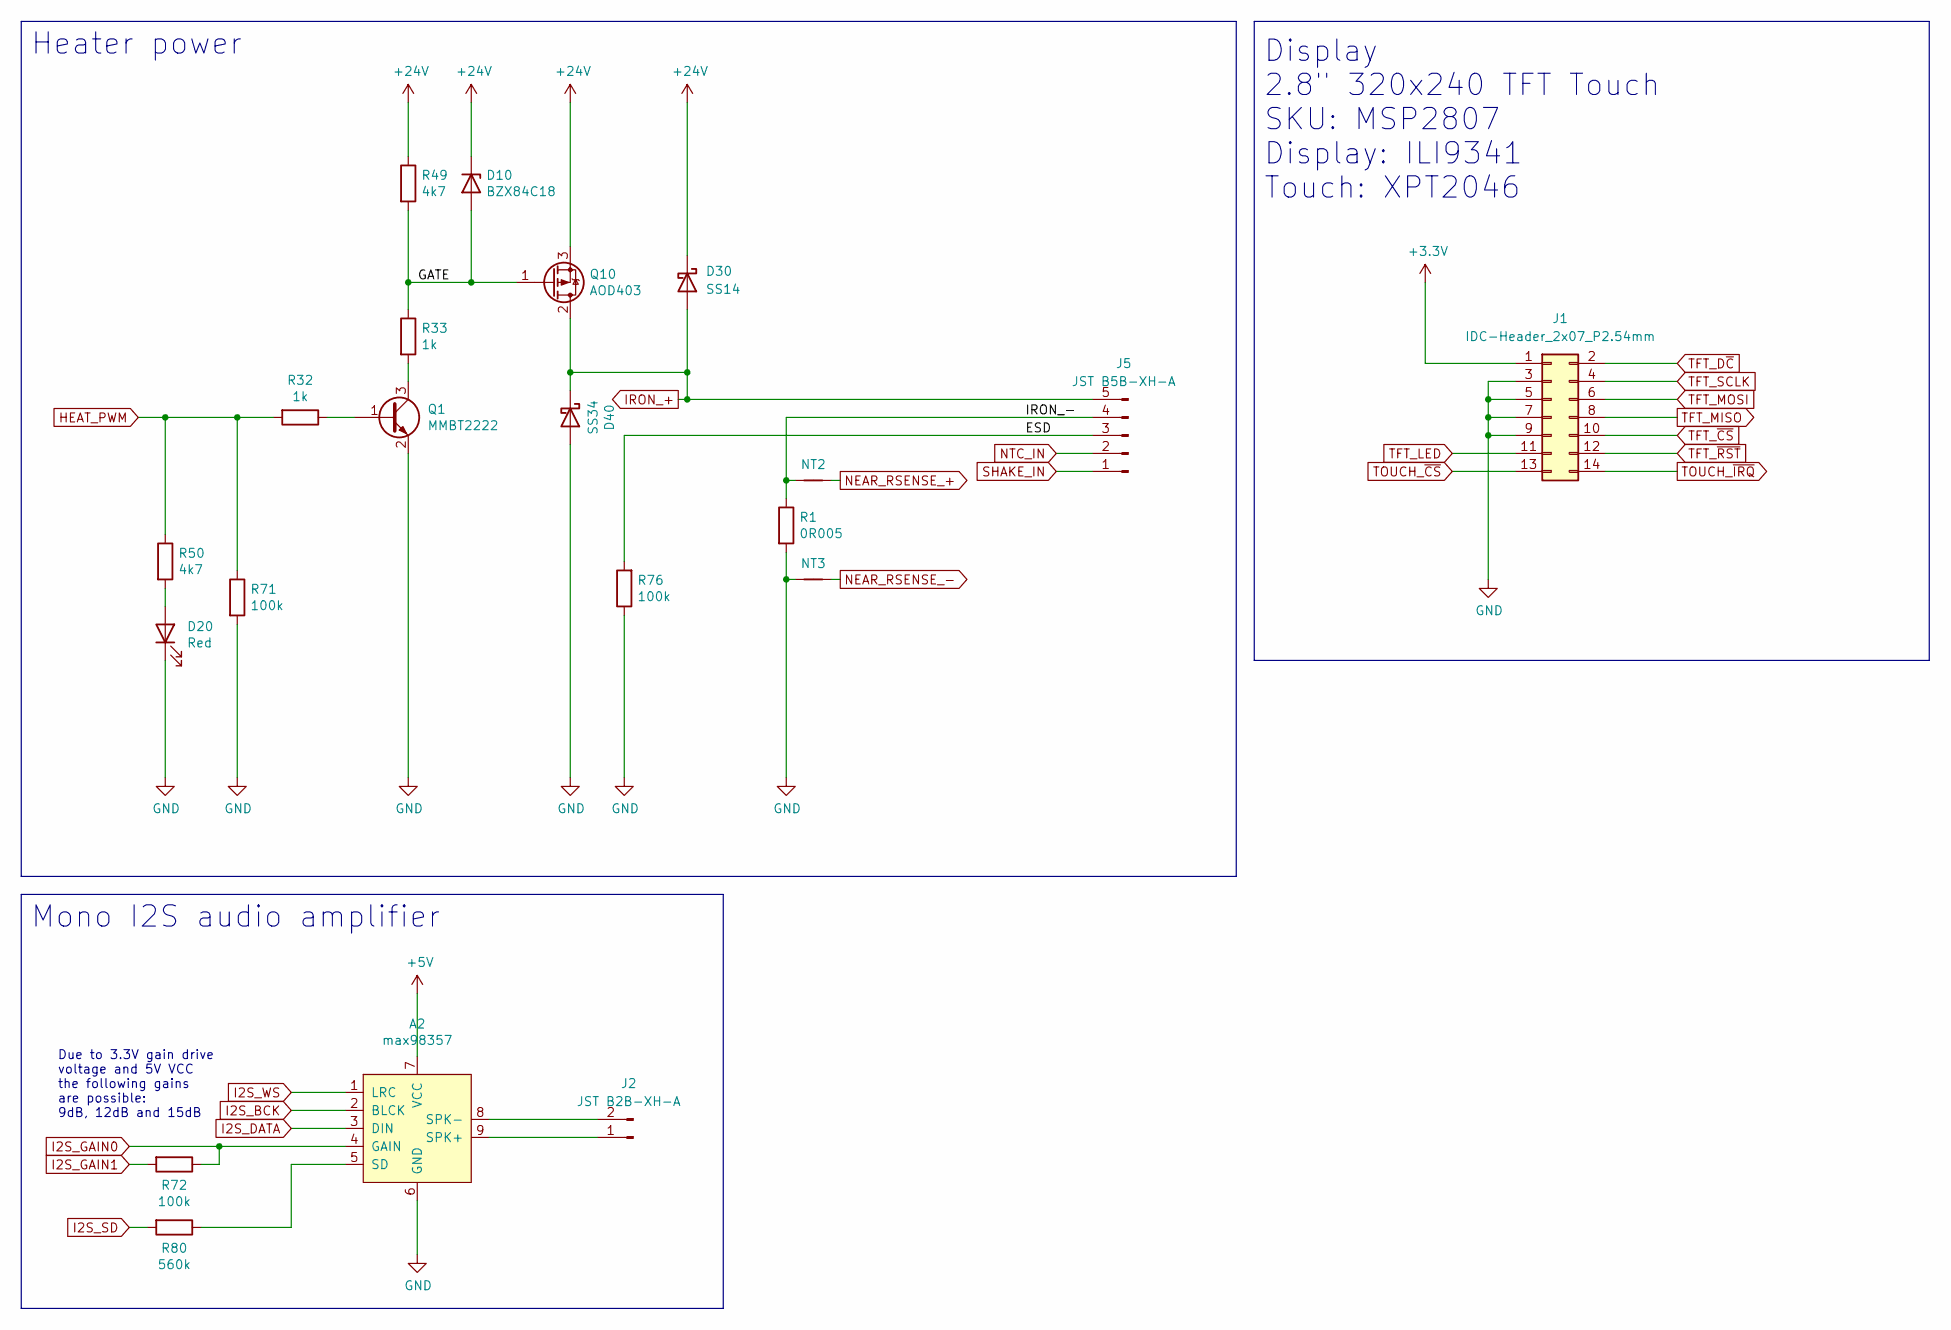
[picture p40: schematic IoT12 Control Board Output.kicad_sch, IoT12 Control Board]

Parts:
A2: max98357
D10: BZX84C18; SOT-23
D20: Red; LED_0805_2012Metric_Pad1.15x1.40mm_HandSolder
D30: SS14; D_SMA
D40: SS34; D_SMA
J1: IDC-Header_2x07_P2.54mm; IDC-Header_2x07_P2.54mm_Vertical
J2: JST B2B-XH-A; JST_XH_B2B-XH-A_1x02_P2.50mm_Vertical
J5: JST B5B-XH-A; JST_XH_B5B-XH-A_1x05_P2.50mm_Vertical
NT2, NT3: NetTie-2_SMD_Pad0.5mm
Q1: MMBT2222; SOT-23
Q10: AOD403; TO-252-2
R1: 0R005; R_2512_6332Metric_Pad1.40x3.35mm_HandSolder
R32, R33: 1k; R_0805_2012Metric_Pad1.20x1.40mm_HandSolder
R49, R50: 4k7; R_0805_2012Metric_Pad1.20x1.40mm_HandSolder
R71, R72, R76: 100k; R_0805_2012Metric_Pad1.20x1.40mm_HandSolder
R80: 560k; R_0805_2012Metric_Pad1.20x1.40mm_HandSolder

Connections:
+3.3V: J1.1; also elsewhere on the board
+5V: A2.7 (VCC); also elsewhere on the board
+24V: D10.3 (K), D30.1 (K), Q10.3 (S), R49.1; also elsewhere on the board
/Output/ESD: J5.3, R76.2
/Output/GATE: D10.1 (A), Q10.1 (G), R33.1, R49.2
/Output/IRON_-: J5.4, NT2.1, R1.1
GND: A2.6 (GND), D20.1 (K), D40.2 (A), J1.3, J1.5, J1.7, J1.9, NT3.1, Q1.2 (E), R1.2, R71.2, R76.1; also elsewhere on the board
HEAT_PWM: R32.2, R50.1, R71.1; also elsewhere on the board
I2S_BCK: A2.2 (BLCK); also elsewhere on the board
I2S_DATA: A2.3 (DIN); also elsewhere on the board
I2S_GAIN0: A2.4 (GAIN), R72.1; also elsewhere on the board
I2S_GAIN1: R72.2; also elsewhere on the board
I2S_SD: R80.2; also elsewhere on the board
I2S_WS: A2.1 (LRC); also elsewhere on the board
IRON_+: D30.2 (A), D40.1 (K), J5.5, Q10.2 (D); also elsewhere on the board
NEAR_RSENSE_+: NT2.2; also elsewhere on the board
NEAR_RSENSE_-: NT3.2; also elsewhere on the board
NTC_IN: J5.2; also elsewhere on the board
unnamed: A2.5 (SD), R80.1
unnamed: A2.9 (SPK+), J2.1
unnamed: A2.8 (SPK-), J2.2
unnamed: D20.2 (A), R50.2
unnamed: Q1.1 (B), R32.1
unnamed: Q1.3 (C), R33.2
SHAKE_IN: J5.1; also elsewhere on the board
TFT_D~C: J1.2; also elsewhere on the board
TFT_LED: J1.11; also elsewhere on the board
TFT_MISO: J1.8; also elsewhere on the board
TFT_MOSI: J1.6; also elsewhere on the board
TFT_SCLK: J1.4; also elsewhere on the board
TFT_~CS: J1.10; also elsewhere on the board
TFT_~RST: J1.12; also elsewhere on the board
TOUCH_~CS: J1.13; also elsewhere on the board
TOUCH_~IRQ: J1.14; also elsewhere on the board

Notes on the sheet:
Heater power
Due to 3.3V gain drive voltage and 5V VCC the following gains are possible: 9dB, 12dB and 15dB
Mono I2S audio amplifier
Display 2.8" 320x240 TFT Touch SKU: MSP2807 Display: ILI9341 Touch: XPT2046

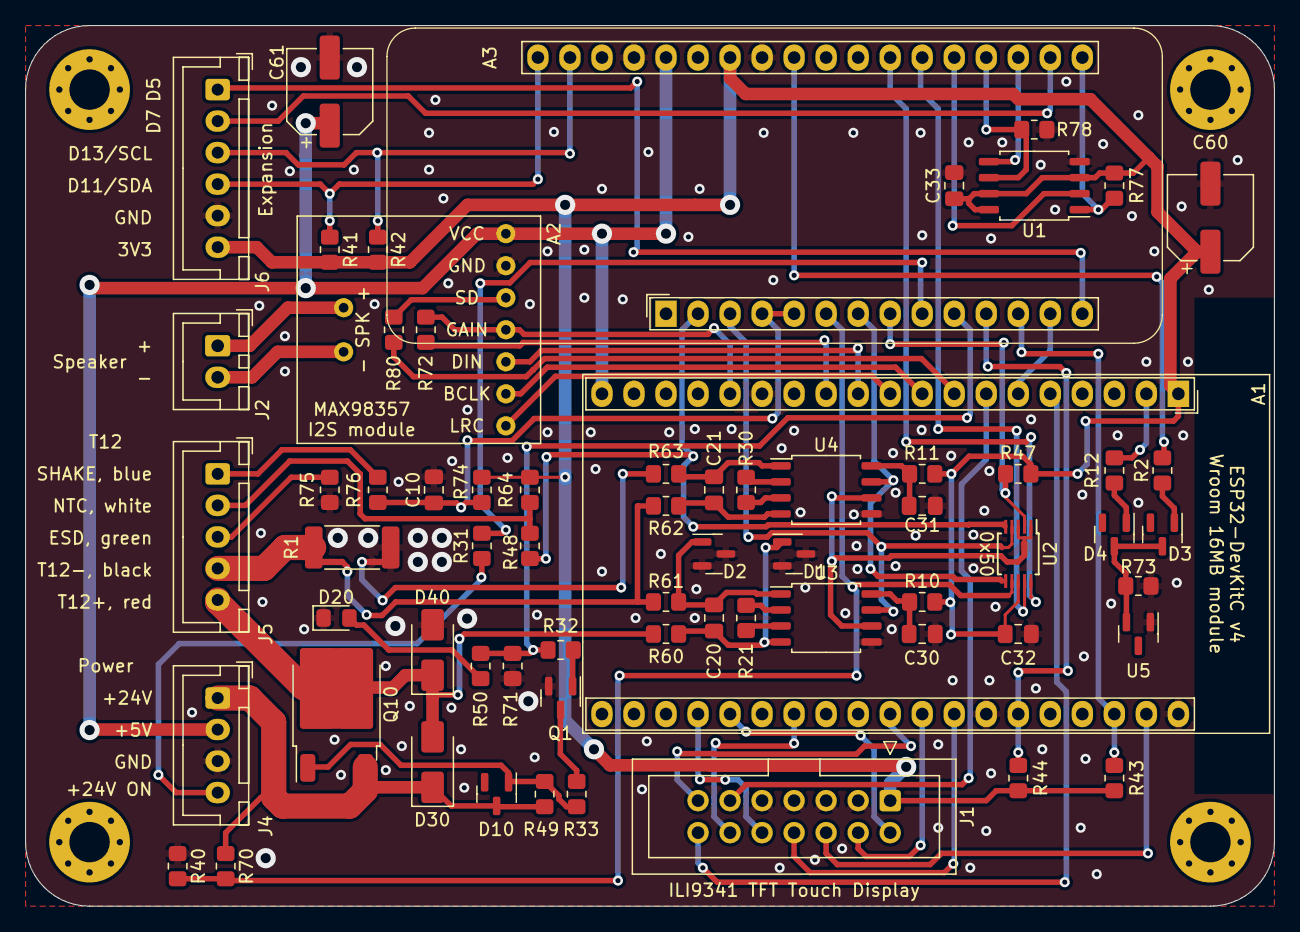
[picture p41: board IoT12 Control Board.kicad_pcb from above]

Board: 2 copper layers, 99.1 x 69.9 mm, 73 parts (0 on the bottom side), 71 nets.

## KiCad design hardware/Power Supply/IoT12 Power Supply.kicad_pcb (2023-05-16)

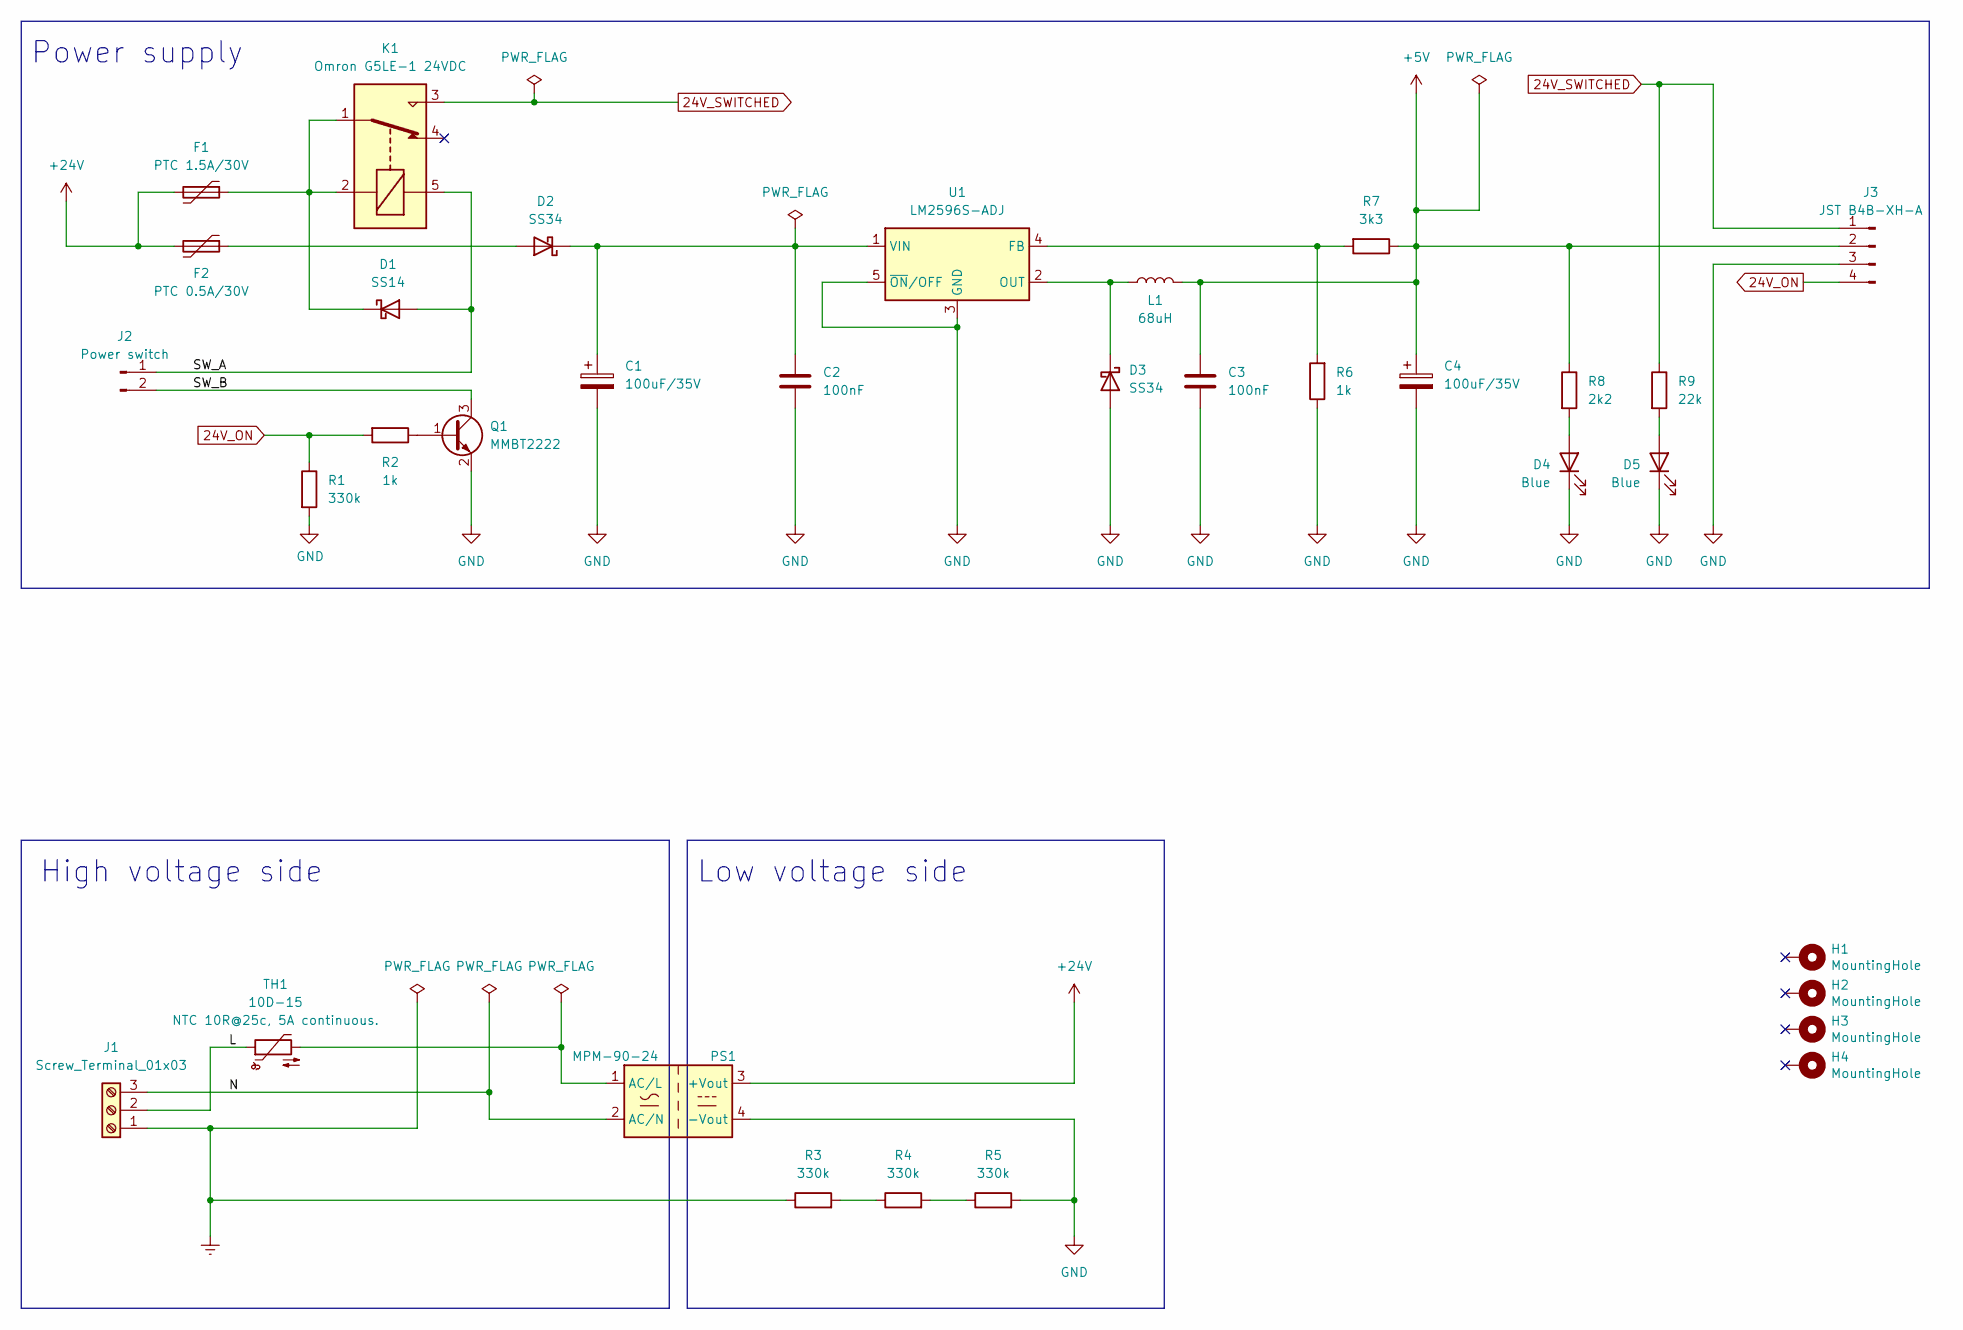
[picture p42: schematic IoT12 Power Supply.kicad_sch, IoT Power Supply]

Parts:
C1, C4: 100uF/35V; CP_Elec_6.3x7.7
C2, C3: 100nF; C_0805_2012Metric_Pad1.18x1.45mm_HandSolder
D1: SS14; D_SMA
D2, D3: SS34; D_SMA
D4, D5: Blue; LED_0805_2012Metric_Pad1.15x1.40mm_HandSolder
F1: PTC 1.5A/30V; RV_Disc_D9mm_W3.3mm_P5mm
F2: PTC 0.5A/30V; RV_Disc_D7mm_W3.4mm_P5mm
H1, H2, H3, H4: MountingHole; MountingHole_3.2mm_M3_Pad_Via
J1: Screw_Terminal_01x03; TerminalBlock_Weidmueller-PM-5.08-03-90-3.5SN-BK-BX
J2: JST B2B-XH-A; JST_XH_B2B-XH-A_1x02_P2.50mm_Vertical
J3: JST B4B-XH-A; JST_XH_B4B-XH-A_1x04_P2.50mm_Vertical
K1: Omron G5LE-1 24VDC; Relay_SPDT_Omron-G5LE-1
L1: 68uH; L_12x12mm_H8mm
PS1: MPM-90-24; Converter_ACDC_MeanWell_MPM-90-xx_THT
Q1: MMBT2222; SOT-23
R1, R3, R4, R5: 330k; R_0805_2012Metric_Pad1.20x1.40mm_HandSolder
R2, R6: 1k; R_0805_2012Metric_Pad1.20x1.40mm_HandSolder
R7: 3k3; R_0805_2012Metric_Pad1.20x1.40mm_HandSolder
R8: 2k2; R_0805_2012Metric_Pad1.20x1.40mm_HandSolder
R9: 22k; R_0805_2012Metric_Pad1.20x1.40mm_HandSolder
TH1: 10D-15; RV_Disc_D15.5mm_W4.5mm_P7.5mm
U1: LM2596S-ADJ; TO-263-5_TabPin3

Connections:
24V_ON: J3.4, R1.1, R2.2
24V_SWITCHED: J3.1, K1.3, R9.1
+5V: C3.1, C4.1, J3.2, L1.2, R7.1, R8.1
+24V: F1.2, F2.2, PS1.3 (+Vout)
/L: J1.2, TH1.1
/N: J1.3, PS1.2 (AC/N)
/SW_A: D1.2 (A), J2.1, K1.5
/SW_B: J2.2, Q1.3 (C)
Earth: J1.1, R3.1
GND: C1.2, C2.2, C3.2, C4.2, D3.2 (A), D4.1 (K), D5.1 (K), J3.3, PS1.4 (-Vout), Q1.2 (E), R1.2, R5.2, R6.1, U1.3 (GND), U1.5 (~ON/OFF)
unnamed: D1.1 (K), F1.1, K1.1, K1.2
unnamed: D2.2 (A), F2.1
unnamed: C1.1, C2.1, D2.1 (K), U1.1 (VIN)
unnamed: D3.1 (K), L1.1, U1.2 (OUT)
unnamed: D4.2 (A), R8.2
unnamed: D5.2 (A), R9.2
unnamed: PS1.1 (AC/L), TH1.2
unnamed: Q1.1 (B), R2.1
unnamed: R3.2, R4.1
unnamed: R4.2, R5.1
unnamed: R6.2, R7.2, U1.4 (FB)

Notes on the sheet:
Low voltage side
Power supply
High voltage side

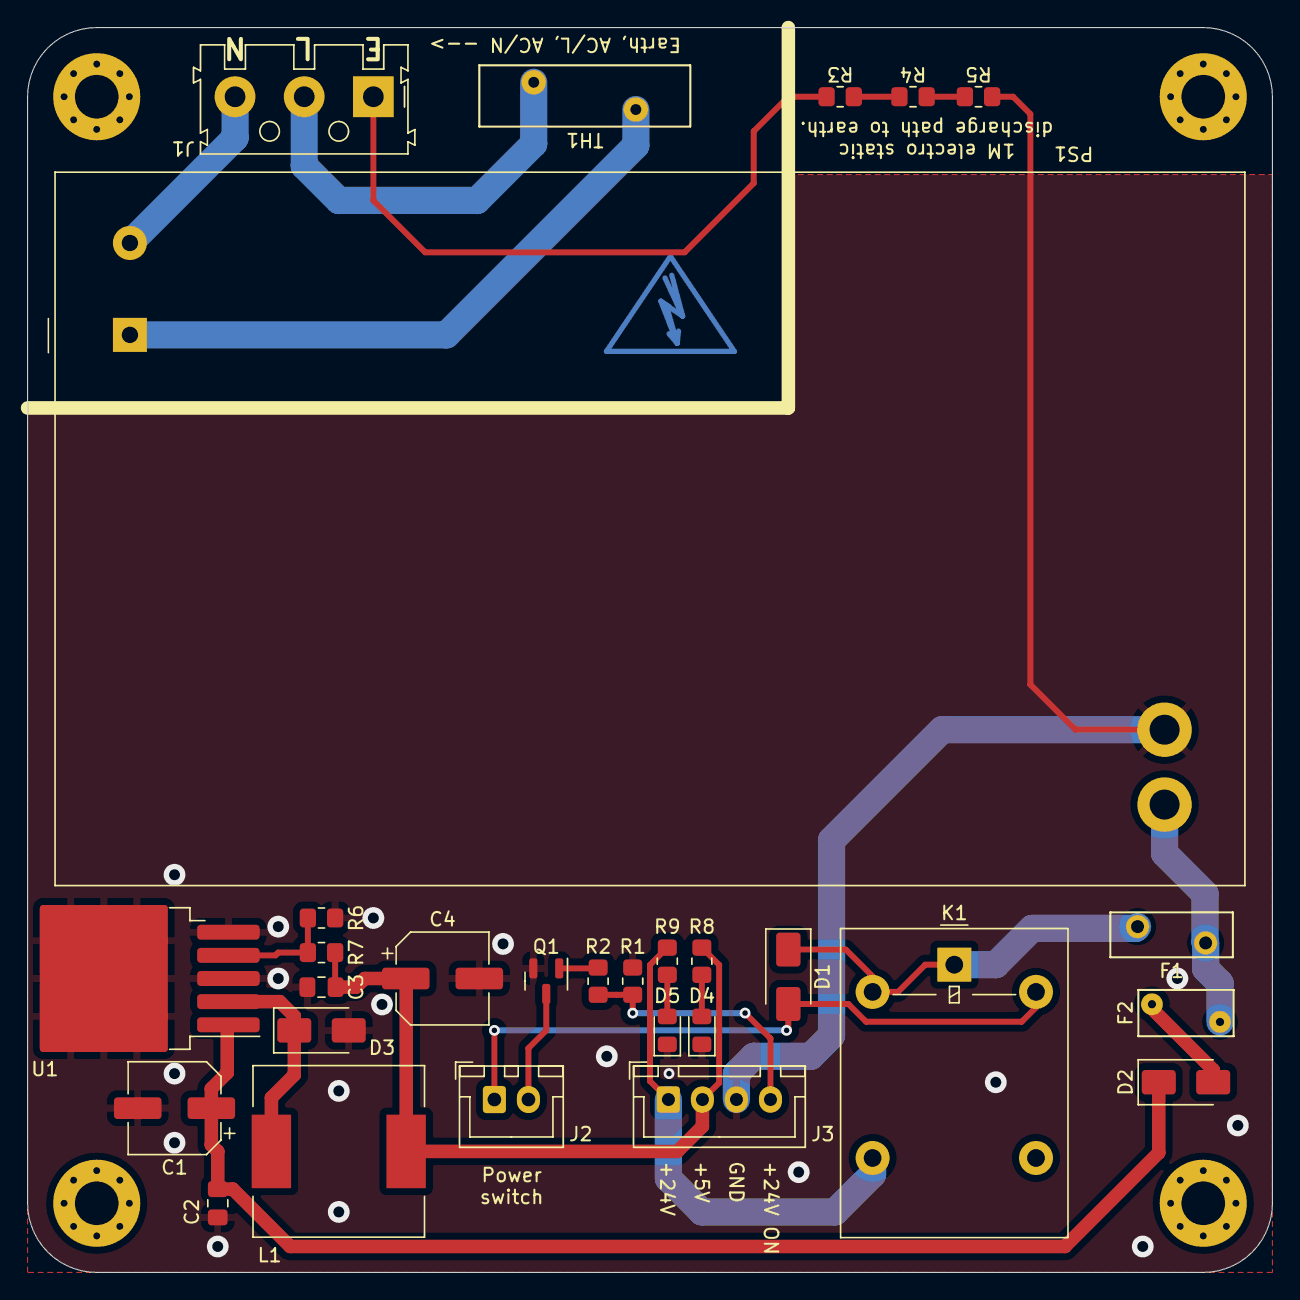
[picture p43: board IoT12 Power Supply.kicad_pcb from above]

Board: 2 copper layers, 91.4 x 91.4 mm, 33 parts (0 on the bottom side), 21 nets.

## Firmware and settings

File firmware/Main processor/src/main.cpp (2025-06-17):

/*

Copyright 2021-2025 Marc Ketel
SPDX-License-Identifier: Apache-2.0

*/

#include <esp32-hal-cpu.h>

#include <Wire.h>

#include <IoAbstraction.h>
#include <TaskManagerIO.h>

#include "HeatController.h"
#include "config.h"
#include "display.h"
#include "main.h"
#include "webserverc.h"
#include "wific.h"

volatile int encoderValue = 30;
void onEncoderChange(int newValue) {
    RequestDrawDisplay();

    if (newValue > 0 && encoderValue < 600) {
        encoderValue += 5;
    }

    if (newValue < 0 && encoderValue > -10) {
        encoderValue -= 5;
    }

    /*
    if (newValue < 0)
        Serial.println("down");
    else
        Serial.println("up");
    */

    float celsius = encoderValue;

    HeatController.setTargetTemperature(celsius + 273.15f);
}

void onSpinwheelClicked(uint8_t pin, bool heldDown) {
    Serial.print("Button pressed ");
    Serial.println(heldDown ? "Held" : "Pressed");

    /*
  u8g2.beginSimple();
  u8g2.setPowerSave(0);
  */

    if (heldDown == false) {
        HEATER_STATE state = HeatController.getHeaterState();
        if (state == HEATER_STATE::OFF) {
            HeatController.setHeaterState(HEATER_STATE::ON);
        } else {
            HeatController.setHeaterState(HEATER_STATE::OFF);
        }
    }

    /*
    FirmwareVersion_t fv = HeatController.getFirmwareVersion();
    Serial.println(String("Version heatcontroller: ") + String(fv.x) + String(".") + String(fv.y) + String(".") + String(fv.z));

    SerialNumber_t sn = HeatController.getSerialNumber();
    Serial.println(String("Serial number heatcontroller: ") + String(sn.word0, HEX) + String(" ") + String(sn.word1, HEX) + String(" ") + String(sn.word2, HEX) + String(" ") + String(sn.word3, HEX) );

    uint16_t const1 = HeatController.getConst1();
    Serial.println(String("Const1 heatcontroller: 0x") + String(const1, HEX) );

    float const2 = HeatController.getConst2();
    Serial.println(String("Const2 heatcontroller: ") + String(const2, 6));
    */
}

void setup() {
    Wire.begin(SDA, SCL, 400000U);

    Serial.begin(115200);
    Serial.println(F("Booting"));

    setCpuFrequencyMhz(80);
    Serial.println(String(F("CPU freq: ")) + String(ESP.getCpuFreqMHz()) + String(F("MHz")));
    Serial.println(String(F("Flash size: ")) + String(ESP.getFlashChipSize() / 1024 / 1024) + String(F("MiB")));

    DisplaySetup();

    pinMode(PIN_ROT_A, PULLUP);
    pinMode(PIN_ROT_B, PULLUP);
    pinMode(PIN_ROT_SW, PULLUP);
    switches.initialiseInterrupt(ioUsingArduino(), true);
    switches.addSwitch(PIN_ROT_SW, onSpinwheelClicked);
    setupRotaryEncoderWithInterrupt(PIN_ROT_A, PIN_ROT_B, onEncoderChange);
    switches.changeEncoderPrecision(0, 0);

    WificSetup();

    pinMode(PIN_LCD_LED, OUTPUT);
    digitalWrite(PIN_LCD_LED, 1);
    HeatController.init();

    taskManager.scheduleFixedRate(
        200, [] {
            RequestDrawDisplay();
        },
        TIME_MILLIS);
}

void CriticalLoop() {
    HeatController.loop();
    taskManager.yieldForMicros(0);
    yield();
}

void loop() {
    CriticalLoop();
    taskManager.runLoop();

    WiFicLoop();
    WebservercLoop();
    DisplayLoop();
}

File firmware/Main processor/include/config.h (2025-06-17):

/*

Copyright 2021-2025 Marc Ketel
SPDX-License-Identifier: Apache-2.0

*/

#ifndef config_h
#define config_h

extern const char *ssid;
extern const char *password;

extern const char *mqtt_topic_prefix;
extern const char *mqtt_server;
extern const char *mqtt_username;
extern const char *mqtt_password;

extern const char *otapassword;
extern const char *otahostname;

#define PIN_LCD_LED     32
#define PIN_LCD_DATACMD 4
#define PIN_LCD_CE      5
#define PIN_LCD_CLK     18
#define PIN_LCD_RST     2
#define PIN_LCD_DIN     23

#define PIN_HEAT_INT 35

#define PIN_ROT_A  16
#define PIN_ROT_B  17
#define PIN_ROT_SW 33

#define PIN_I2S_CLK  25
#define PIN_I2S_WS   26
#define PIN_I2S_DATA 27

#endif

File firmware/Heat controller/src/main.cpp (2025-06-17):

/*

Copyright 2021-2025 Marc Ketel
SPDX-License-Identifier: Apache-2.0

*/

#include <Arduino.h>
#include <Wire.h>

#include "Heater.h"
#include "Sensor.h"
#include "Setting.h"
#include "WireMinion.h"
#include "main.h"

void HardFault_Handler(void) {
#if defined DEBUG
    __BKPT(3);
#endif
    NVIC_SystemReset();
    for (;;) {
    }
}

void setup() {
    pinMode(0, OUTPUT);  // TP1
    pinMode(1, OUTPUT);  // TP2
    pinMode(9, OUTPUT);  // TP3
    pinMode(10, OUTPUT); // TP4
    pinMode(LED_BUILTIN, OUTPUT);
    digitalWrite(LED_BUILTIN, LOW);

    SerialUSB.begin(115200);

    Wire.begin();
    Wire.setClock(100000);
    WireMinion.init();

    Setting.init();

    I2SGPIO.init();
    Sensor.init();

    Heater.init();
}

void loop() {
    Heater.loop();
    Sensor.loop();
    Setting.loop();
    WireMinion.loop();
}

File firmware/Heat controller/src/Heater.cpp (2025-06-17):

/*

Copyright 2021-2025 Marc Ketel
SPDX-License-Identifier: Apache-2.0

*/
#include <Arduino.h>

#include <QuickPID.h>

#include <NTC.h>
#include <Thermocouple.h>

#include "AdcExternal.h"
#include "AdcInternal.h"
#include "Heater.h"
#include "Setting.h"
#include "WireMinion.h"

HeaterClass::HeaterClass() {
}

NTC ntc;
Thermocouple thermocouple;

float tAmbient = 0;
float tTip = 0;
float tTarget = 0;
float vVINHeatOn = 0;
float vVINHeatOff = 0;
float iIronPowerOff = 0;
float iIronPowerOn = 0;

float heatingFrequency = 5; // This many times per second go through heating and measure cycle.
#define DIV_TCC 1
uint32_t timeHeatingOffMeasureTempUs = 20000; // You have this long to measure things while heating is off.
uint32_t timeHeatingCooldownUs = 1000;        // When heater is 100% on, stop heating this many time before going into off state. This is needed because the heating circuitry needs time to turn off before starting measuring off state.

uint32_t periodHeatAllowed;
uint32_t periodHeatDisabled;
float heatfactor = 0;

volatile bool eventHeatOff = false;
volatile bool eventHeatOn = false;

/*
https://en.wikipedia.org/wiki/PID_controller#Manual_tuning

451C, Kp start of oscillation: 0.025

*/
float Kp = 0.01, Ki = 0.005, Kd = 0.0001;

QuickPID myQuickPID(&tTip, &heatfactor, &tTarget, Kp, Ki, Kd, QuickPID::Action::direct);

void HeaterClass::init(void) {
    myQuickPID.SetOutputLimits(0, 1);
    myQuickPID.SetMode(QuickPID::Control::automatic);

    ntc.SetParameters(3.3,
                      Setting.resistanceNTCPullUp,
                      10000,
                      25 + 273.15,
                      3950);

    // Configure TCC0

    // F: TCC0/WO[6], PA16, D11

    uint32_t totalPeriod = (F_CPU / DIV_TCC / heatingFrequency) - 1;

    // Max 24-bit period.
    if (totalPeriod > 1 << 24) {
        totalPeriod = 1 << 24;
    }

    periodHeatDisabled = timeHeatingOffMeasureTempUs * (F_CPU / DIV_TCC / 1000000);
    periodHeatAllowed = totalPeriod - periodHeatDisabled;

    // Enable and configure generic clock generator 4
    GCLK->GENCTRL.reg = GCLK_GENCTRL_IDC |         // Improve duty cycle
                        GCLK_GENCTRL_GENEN |       // Enable generic clock gen
                        GCLK_GENCTRL_SRC_DFLL48M | // Select 48MHz as source
                        GCLK_GENCTRL_ID(4);        // Select GCLK4
    while (GCLK->STATUS.bit.SYNCBUSY)
        ; // Wait for synchronization

    // Set clock divider of 1 to generic clock generator 4
    GCLK->GENDIV.reg = GCLK_GENDIV_DIV(DIV_TCC) | // Divide 48 MHz by 1
                       GCLK_GENDIV_ID(4);         // Apply to GCLK4 4
    while (GCLK->STATUS.bit.SYNCBUSY)
        ; // Wait for synchronization

    // Enable GCLK4 and connect it to TCC0 and TCC1
    GCLK->CLKCTRL.reg = GCLK_CLKCTRL_CLKEN |       // Enable generic clock
                        GCLK_CLKCTRL_GEN_GCLK4 |   // Select GCLK4
                        GCLK_CLKCTRL_ID_TCC0_TCC1; // Feed GCLK4 to TCC0/1
    while (GCLK->STATUS.bit.SYNCBUSY)
        ; // Wait for synchronization

    // Divide counter by 1 giving 48 MHz (20.83 ns) on each TCC0 tick
    TCC0->CTRLA.reg |= TCC_CTRLA_PRESCALER(TCC_CTRLA_PRESCALER_DIV1_Val);

    // Use "Normal PWM" (single-slope PWM): count up to PER, match on CC[n]
    TCC0->WAVE.reg = TCC_WAVE_WAVEGEN_NPWM; // Select NPWM as waveform
    while (TCC0->SYNCBUSY.bit.WAVE)
        ; // Wait for synchronization

    // Set the period (the number to count to (TOP) before resetting timer)
    TCC0->PER.reg = periodHeatAllowed;
    while (TCC0->SYNCBUSY.bit.PER)
        ;

    // Set PWM signal off
    // n for CC[n] is determined by n = x % 4 where x is from WO[x]
    TCC0->CC[2].reg = 0;
    while (TCC0->SYNCBUSY.bit.CC2)
        ;

    // Configure PA16 (D11 on Arduino M0) to be output
    PORT->Group[PORTA].DIRSET.reg = PORT_PA16; // Set pin as output
    PORT->Group[PORTA].OUTCLR.reg = PORT_PA16; // Set pin to low

    // Enable the port multiplexer for PA16
    PORT->Group[PORTA].PINCFG[16].reg |= PORT_PINCFG_PMUXEN;

    // Connect TCC0 timer to PA16. Function F is TCC0/WO[6] for PA16.
    // Odd pin num (2*n + 1): use PMUXO
    // Even pin num (2*n): use PMUXE
    PORT->Group[PORTA].PMUX[8].reg = PORT_PMUX_PMUXE_F;

    TCC0->INTENSET.reg =
        TCC_INTENSET_CNT;

    NVIC_EnableIRQ(TCC0_IRQn);

    // Enable output (start PWM)
    TCC0->CTRLA.reg |= (TCC_CTRLA_ENABLE);
    while (TCC0->SYNCBUSY.bit.ENABLE)
        ; // Wait for synchronization
}

void TCC0_Handler() {
    static uint32_t periodHeatEnabled = 0;

    if (TCC0->INTFLAG.bit.CNT) {
        TCC0->INTFLAG.bit.CNT = 1;

        static uint8_t state = 0;

        if (state == 0) {
            // Current state is (possible) heating, next state is off for measure.
            if (periodHeatEnabled > 0) {
                eventHeatOn = true;
            }

            state = 1;
            digitalWrite(9, HIGH);
            TCC0->PERB.reg = periodHeatDisabled;
            while (TCC0->SYNCBUSY.bit.PERB)
                ;
            TCC0->CCB[2].reg = 0;
            while (TCC0->SYNCBUSY.bit.CCB2)
                ;
        } else {
            eventHeatOff = true;
            state = 0;
            digitalWrite(9, LOW);
            TCC0->PERB.reg = periodHeatAllowed;

            if (heatfactor > 1) {
                heatfactor = 1;
            }

            if (heatfactor < 0) {
                heatfactor = 0;
            }

            if (Setting.heaterState != HEATER_STATE::ON) {
                heatfactor = 0;
            }

            periodHeatEnabled = (periodHeatAllowed - (timeHeatingCooldownUs * (F_CPU / DIV_TCC / 1000000))) * heatfactor;

            while (TCC0->SYNCBUSY.bit.PERB)
                ;
            TCC0->CCB[2].reg = periodHeatEnabled;
            while (TCC0->SYNCBUSY.bit.CCB2)
                ;
        }
    }
}

float readThermocoupleVoltage() {
    float v = ADCExternal.readChannel(AIN_EXTERNAL_ADC_TEMP) / Setting.gainHeaterTemperatureAmplifier;
    v -= Setting.thermocoupleInputOffsetVoltage;
    return v;
}

float readVin() {
    return ADCExternal.readChannel(AIN_EXTERNAL_ADC_VIN) / Setting.gainVSupplyResistorDivider;
}
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

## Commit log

2021-02-06 Inline stl renderer does not work for me.
    [Knob1-lowres.stl]
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2021-04-03 Added register usage overview.
    [Register usage overview.ods]
2021-04-04 Updated register usage overview.
    [Register usage overview.ods]
2021-04-05 Changed registers.
    [Register usage overview.ods]
2021-09-12 Remove capacitor and resistor from usb shield.
    [IoT12 Control Board Brain.sch, IoT12 Control Board Input.sch, IoT12 Control Board Output.sch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]
2021-09-25 Next attempt building case.
    [C14-socket-cutter.step, Case.FCStd, gx12-cutter.FCStd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]
2021-09-25 PCB component placement change.
    [IoT12 Control Board Brain.sch, IoT12 Control Board Input.sch, IoT12 Control Board Output.sch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]
2021-09-26 Floating pcb supports do not work in real life.
    [Case.FCStd]
2021-09-26 Enlarge hole for knob.
    [Case.FCStd]
2021-09-26 Add LCD pin labels. Add testpoints heat controller.
    [IoT12 Control Board Brain.sch, IoT12 Control Board Input.sch, IoT12 Control Board Output.sch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]
2021-10-01 Progress building case.
    [1x ac-parts-shield.stl, 1x case.stl, 1x lid.stl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]
2021-10-01 Lid stl.
    [1x lid.stl]
2021-10-02 Next iteration after print.
    [1x case.stl, Case.FCStd]
2021-10-08 Add: this PCB is not safe to use.
    [IoT12 Power Supply.kicad_pcb, IoT12 Power Supply.sch]
2021-10-08 Add BOM and gerber files.
    [IoT12 Power Supply-B_Cu.gbl, IoT12 Power Supply-B_Mask.gbs, IoT12 Power Supply-B_SilkS.gbo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]
2021-10-21 Remove all lower power supply options.
    [IoT12 Power Supply-B_Cu.gbl, IoT12 Power Supply-B_Mask.gbs, IoT12 Power Supply-B_Paste.gbp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]
2021-11-07 Add knob.
    [1x knob R3.15mm.stl, Case.FCStd, Knob.FCStd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]
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2021-11-21 Replace bang-bang with PID controller.
    [Heater.cpp]
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2021-11-27 Move hardware files to subdirectory
    [IoT12 Control Board Brain.sch, IoT12 Control Board Input.sch, IoT12 Control Board Output.sch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]
2021-11-27 Move firmware files to subdirectory
    [Register usage overview.ods]
2021-11-27 Move 3d files to subdirectory
    [1x ac-parts-shield.stl, 1x case.stl, 1x knob R3.15mm.stl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]
2022-01-28 Kicad 5 to 6 upgrade.
    [IoT12 Control Board Brain.kicad_sch, IoT12 Control Board Brain.sch, IoT12 Control Board Input.kicad_sch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]
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2022-08-22 Errata for PCB V2.1
2022-11-02 Open sch and brd, delete *.sch and *.brd, then save in Kicad 6.0.9 to resolve errors while saving.
    [IoT12 Control Board Brain.kicad_sch, IoT12 Control Board.kicad_pcb]
2022-11-19 Start of next iteration.
    [Display Adapter-B_Cu.gbl, Display Adapter-B_Mask.gbs, Display Adapter-B_Paste.gbp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]
2022-11-20 Ignore .zip
    [Display Adapter-B_Cu.gbl, Display Adapter-B_Mask.gbs, Display Adapter-B_Paste.gbp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]
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2022-12-10 Add PDF. Enlarge F1 pad size.
    [IoT12 Power Supply-B_Cu.gbl, IoT12 Power Supply-B_Mask.gbs, IoT12 Power Supply-B_Paste.gbp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]
2022-12-10 Make more room around F1.
    [IoT12 Power Supply-B_Cu.gbl, IoT12 Power Supply-B_Mask.gbs, IoT12 Power Supply-B_Paste.gbp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]
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2022-12-10 Corrected footprint for INA826AID.
    [IoT12 Control Board Input.kicad_sch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]
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2023-05-16 Update Power Supply project to Kicad 7.0.2
    [IoT12 Power Supply-B_Cu.gbl, IoT12 Power Supply-B_Mask.gbs, IoT12 Power Supply-B_Paste.gbp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]
2023-05-16 Update Display Adapter project to Kicad 7.0.2
    [Display Adapter-B_Cu.gbl, Display Adapter-B_Mask.gbs, Display Adapter-B_Paste.gbp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]
2023-05-16 Update Control Board project to Kicad 7.0.2
    [IoT12 Control Board Brain.kicad_sch, IoT12 Control Board Input.kicad_sch, IoT12 Control Board Output.kicad_sch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]
2023-05-16 Fix gerber directory.
    [Display Adapter-B_Cu.gbl, Display Adapter-B_Mask.gbs, Display Adapter-B_Paste.gbp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]
2023-05-18 Clarify use of ESP32-WROOM-32E.
    [IoT12 Control Board Brain.kicad_sch, IoT12 Control Board.kicad_pcb]
2023-09-24 Redesign 3d-printable case.
    [1x ac-parts-shield.stl, 1x case.stl, 1x hv shield.stl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]
2023-09-24 Change hv-shield dimension.
    [1x hv shield.stl, Case.FCStd]
2023-09-29 Change 3d design after first print.
    [1x case.stl, 1x hv shield.stl, 1x lid.stl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]
2023-09-30 Next iteration on 3d design.
    [1x hv shield.stl]
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2026-10-26 M2: move the heat controller to the V2.2 pin map, drive 24V_ON, and remove the V1 I2S and internal-ADC paths.
2026-10-26 M3: keep the I2C minion bus on sercom2 (PA08/PA09) and remove I2C_ADDRESS_EEPROM from config.h
2026-11-01 M3: fix HEAT_INT to D4 (PA14) and run the minion bus at 100 kHz
    PIN_HEAT_INT was D2, which is PA08 (ESP32_SDA) on the mzeroUSB
    variant. pinMode(OUTPUT) sets PINCFG to PORT_PINCFG_INEN and clears
    PMUXEN, so the SERCOM2 SDA mux was disabled and the slave never
    matched its address. Move HEAT_INT to D4 (PA14) and keep the minion
    bus on D2/D3 (PA08/PA09).
    Run the ESP32 I2C master at 100 kHz: SERCOM::initSlaveWIRE() never
    sets CTRLA.SPEED, so the SAMD21 slave stays in standard mode.
    Use 1UL in raiseInterrupt(); 1 << 31 is undefined behaviour.
    Verified on V2.2 hardware: ACK on 0x2A, version 2026.11.1, reads of
    0x00, 0x01, 0x11, 0x40, 0x41, 0x80, 0xF8 and 0xF9, a target
    write/readback, and INT_RE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
2026-11-01 Add shared SerialCli, EventLog and Log libraries
    SerialCli is a push-driven command parser: feed(char) per byte, an
    output callback, runtime command registration, in-place tokenization
    and a built-in help. It has no Arduino dependency, so one source
    serves the SAMD21 and the ESP32; the command table and input buffer
    sizes are set per target with -DCLI_MAX_COMMANDS and
    -DCLI_INPUT_BUFFER_SIZE.
    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
2026-11-01 M3b/M3c: add the Serial CLI to the heat controller and remove the periodic prints
    M3b: wire SerialCli into setup()/loop() with a SerialUSB output
    callback that returns early when the host has not opened the port, so
    a missing terminal cannot stall the heating cycle. Add version,
    uptime, mem, events and reboot (two-step, deferred to loop()).
    M3c: delete the ~20-line print block in the heating cycle and the
    remaining prints in AdcExternal, AnalogComparator and Setting. The
    values move to file scope and are exposed through HeaterClass::status()
    and AdcExternal::readChannelRaw(); the CLI reads them on demand.
    Settings save/load/default and heater on/off/fault become EventLog
    records.
    Add the r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
2026-11-01 M1/M2/M2b/M2c: restructure the ESP32 firmware, drop the dead hardware and add the Serial CLI
    M1: split src/ into app/, hardware/ and services/ and add a
    composition root (AppSetup/AppLoop in App.cpp); main.cpp is four
    lines.
    M2: remove the rotary encoder, the 5110/U8g2 display, IoAbstraction
    and TaskManagerIO. display.cpp is a no-op until M3.
    M2b: wire SerialCli into the composition root and add version, uptime,
    mem, events and reboot.
    M2c: remove every periodic print. The 32-bit interrupt bitmask print
    ran on every HEAT_INT (about 50 Hz) and is replaced by lastInterrupt,
    readable through heat and heat int. The boot banner, the button print,
    the HTTP server print and the OTA per-chunk pro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
2026-11-01 M3: drive the ILI9341 panel and XPT2046 touch with LovyanGFX
    Add the display and touch driver, the display and touch CLI commands, and
    a home panel that redraws only the fields that changed.
2026-11-01 M4: report flash identity and status over the CLI
    - Add a raw-SPI helper for commands the Adafruit transport cannot issue,
    because it has no dummy-byte support.
    - Add flash info: JEDEC ID, size, 64-bit unique ID, decoded status 1/2/3
    and ready state.
    - Report block protect and lock bits as none, partial or all, since the
    exact range depends on the datasheet table of the fitted device.
    - Update the plan with the measured unique ID and status values.
2026-11-02 M5: store the settings as JSON on the LittleFS volume
    - Replace the EEPROM struct, the CRC and the union with a JSON document
    on LittleFS. The keys are the SettingClass member names and the target
    temperature stays in K, the same unit as register 0x80.
    - Copy /settings.json to /settings.json.bak before each save, then write
    the new primary in one lfs_file_write. A partial write is invalid JSON,
    so the backup is always the last completed save.
    - Load the primary first and fall back to the backup only when the primary
    is missing or invalid. A key that is missing from the file keeps its
    default.
    - Extend the settings command with get, set, save, load, defaults and
    file. The dump p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
2026-11-02 M5: fix the float formatter and keep the last valid backup
    - Scale in double and uint64_t in CliFormat::formatFloat. The uint32_t
    product overflowed at 4294.967296 with six decimals, so 10000 printed
    as 4294.967295, and the float product lost the low digits, so 373.15
    printed as 373.149984.
    - Only copy a valid primary to /settings.json.bak, so a corrupt primary
    cannot destroy the last good copy.
    - Mark M5 verified on V2.2 hardware in the plan.
2026-11-02 M6: read the ADS1115 only and report the write result
    Heat controller:
    - Read TEMP, NTC, IRON_CURRENT and VIN from the ADS1115 over Wire, with
    ADC_RDY as the conversion-ready interrupt and a 5 ms per-channel timeout.
    - Delete AnalogComparator; SHAKE becomes a digital input in M8.
    - Keep the SAMD21 internal ADC as a read-only diagnostic. `adc` shows the
    ADS1115 value, the internal value and the absolute difference in V.
    - Add `adc raw` and `sensor offset [<volts>]`.
    Main processor:
    - Return the writeRegister result from setHeaterState and
    setTargetTemperature and print `heat: write failed (%u)` on failure.
2026-11-02 M7: add the minion register protocol and link supervision
    - Add the register map table and the minion, regs, int, and link commands.
    - Force the heater off and raise INT_LINK_TIMEOUT when no heartbeat arrives
    within the link timeout.
    - Add register 0x12 for the link timeout.
    - Add heater on|off, setpoint, and pid gain setters.
    - Read REGISTER_HEATER_STATE every second as the link heartbeat.
    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
2026-11-03 M4: add the touch UI with a flicker-free Variant C home screen
    - Add Ui.cpp/Ui.h: the zone table, hit-test, 20 ms sampling, 30 ms debounce, press/hold/repeat, and the 0-450 C setpoint clamp.
    - Draw the Variant C home screen with Logisoso 24/46 (U8g2) and a real degree sign; the tip value and setpoint use %5.1f so they never move.
    - Show the actual PWM duty in green instead of the word ON.
    - Redraw only the fields and buttons that changed. DisplayRequestDraw() marks the state dirty instead of forcing a full repaint, and each button is diffed on its own pressed state.
    - Mirror the touch x axis by swapping y_min/y_max; the XPT2046 is mounted 180 degrees to the panel.
    - Remove the font demo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
2026-11-04 M7: add the network services, the web UI and the touchscreen screenshot
    Replace the legacy wific/webserverc/ota/config modules with
    HomeWiFiService, WebServerService, WebConfigStore, MdnsService and
    DeviceName. The device runs a station-first WiFi state machine with an
    NVS network array, an AP portal with a generated WPA2 password, mDNS,
    SSE live state and OTA upload.
    Add the embedded web UI (index.html, app.js, style.css), generated into a
    gzip header by tools/generate_webui_header.py, with a Live card, a
    Display card and the stream retry logic.
    Add /api/screenshot: a chunked RGB565 readback of the panel, 16 rows per
    strip, guarded by a display mutex so a draw cannot tear the capture. The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
2026-11-06 M9: add touchscreen calibration and the touch test screen
    - Add the TOUCH carousel screen with the eight stored raw corner values.
    - Add the four-corner calibration: 500 ms hold, bilinear extrapolation to the
    native corners, and a four-button validation that restarts on a miss.
    - Store the eight values in NVS and add touch calibrate|abort|reset.
    - Add the TEST screen with a crosshair, mapped and raw coordinates, an EXIT
    button and a 30 s timeout.
    - Use the measured four-corner default (120,3600 / 210,170 / 3860,3645 /
    3900,175) when no calibration is stored.
2026-11-06 Add supply voltage and iron current and close the remaining gaps
    - Add minion registers 0x43 SUPPLY_VOLTAGE and 0x44 IRON_CURRENT and show
    both on the web page.
    - Add the missing 0x42, 0x43 and 0x44 rows to the heat controller README.
    - Clamp settings set targetTemperatureHeater and report the stored value.
    - Add the git commit to /api/device and the Device card.
    - Keep CLI_MAX_COMMANDS at 24 for the heat controller and 32 for the main
    processor.
    - Force the hour form in the lifetime TOTAL row.
    - Add the main processor README and align both READMEs with the code.
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2026-11-07 Add nerd stats to the web page
    Expose the ESP32 and heat controller identity, memory, link, heater and
    shake counters in a Nerd stats card. The page fetches the fixed device
    data once and again when either uptime goes backwards.
    Add diagnostic registers to the heat controller for uptime, reset cause,
    free RAM, event count, board, build, forced-off count, cycle count, ADC
    read time, PID terms and gains, raw PWM, shake state, die temperature,
    VDD, sketch size and free sketch. Read the SAMD21 die temperature and
    I/O supply through the internal ADC.
    Fix the SAMD21 reset cause bit positions, read the soft-AP MAC from
    eFuse so it is valid before the AP starts, and report the free sketch
    space as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
2026-11-07 Harden SHAKE detection and show the standby ramp
    Add a 5-sample median filter to the SHAKE input so a single noise spike does not reset the motion timer. Show the POWER button yellow while the heater target ramps down to standby. Report handle faults only after the raw state has been stable for one second, and keep the POWER start guard on the raw state.
2026-11-07 Add source download to the webui
    Pack the main processor and heat controller source trees into one gzipped tar at build time and serve it from /api/source. The Source card links to the GitHub repository and downloads the archive.
    Generate GitCommit.h from the short git commit so the archive name carries the commit. The build flag approach did not reach the compile command.
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

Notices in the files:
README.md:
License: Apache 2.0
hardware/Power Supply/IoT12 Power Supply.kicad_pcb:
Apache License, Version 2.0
